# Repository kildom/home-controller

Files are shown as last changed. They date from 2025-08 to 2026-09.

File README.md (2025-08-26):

# home-controller

# Najnowsze ustalenia

* Nowy pomysł: Zrobić oddzielny moduł "gateway", zawiera:
  * Step-down 12->5V
  * alt 12V
  * Moduł RS-485
  * Mały mikrokontroler (np. AVR albo STM32C011F4P6) jako gateway między int. UART i RS-485
  * Złącza: GND, in 12V, in alt 12V, out 12V, out 5V, D+, D-, int. UART
  * Dzięki temu znika z tabeli poniżej: RS-485 i alt 12V
  * Gateway może informować local nodes: Output fifo full, voltage: 12V in, out, alt, 5V
* Jednak moduł STM32 zamiast 2 AVRów: [STM32F103C8T6](https://kamami.pl/zestawy-uruchomieniowe-stm32/1192915-kamod-bluepill-plytka-rozwojowa-z-mikrokontrolerem-stm32f103c8t6-kompatybilna-z-weact-bluepill-5906623487998.h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)
  * RS-485 (ten wymaga podłączenia do padów 5V-tolerant)
  * Piny podłączone do kwarca mogą być użyte, ale powinny mieć jednakowy stan, więc są traktowane razem jako jedno wyjście - połączone na płytce.
* Gotowe moduły step-down i RS-485 (ten wymaga podłączenia do padów 5V-tolerant)
* Kabel między-modułowy wymaga 2 przewodów: UART i 5V (opcjonalnie GND)
  * Albo może: zrezygnować z 2 IO na rzecz połączeń między-modułowych (wtedy też można usunąć `Shared RS-485+IO` z poniższej tabeli).
* Zaciski IO mogą być w jednym kawałku: https://mou.sr/4oknD5P
* Tabela z zasobami:

| | szt. | zaciski 230V | zaciski 12V | Pin µC | zaciski 230V | zaciski 12V | Pin µC |
| --- | ---- | --- | --- | --- | --- | --- | --- |
| Common 230V | 1 | 1 | | | 1 | 0 | 0 |
| Relays 230V common | 9 | 1 | | 1 | 9 | 0 | 9 |
| Relays 230V individual | 1 | 2 | | 1 | 2 | 0 | 1 |
| Relays 12V | 1 | | 2 | 1 | 0 | 2 | 1 |
| RS-485 | 1 | | | 3 | 0 | 0 | 3 |
| LED \* | 2 | | 2 | 2 | 0 | 4 | 4 |
| OC | 2 | | 1 | 1 | 0 | 2 | 2 |
| IO | 12 | | 1 | 1 | 0 | 12 | 12 |
| int. UART | 1 | | | 2 | 0 | 0 | 2 |
| GND | 1 | | 2 | | 0 | 2 | 0 |
| 12V | 1 | | 1 | | 0 | 1 | 0 |
| alt 12V | 1 | | 1 | | 0 | 1 | 0 |
| Shared RS-485+OC | 1 | | | \-1 | 0 | 0 | \-1 |
| Shared RS-485+IO | 2 | | | \-1 | 0 | 0 | \-2 |
| | | | | **RAZEM** | **12** | **24** | **31** |
| | | | | MAX | 12 | 24 | 31 |
| | | | | Pozostało | 0 | 0 | 0 |

# Inne

* Obudowa: [Kradex ZD1004J](https://botland.com.pl/obudowy/24954-obudowa-modulowa-kradex-zd1004j-abs-v0-na-szyne-din-652x898x716mm-jasnoszara-5905275033614.html)
* Przekaźniki: FORWARD INDUSTRIAL FRM18A-5
* Zaciski 230V: AK3001/6-KD-5.0/KIES
* Zaciski IO/12V: Phoenix Contact PTSA 0,5/ 8-2,5-Z 1990067
* Zabezpieczenie ESD: Littelfuse SP720
* Mikrokontroller: 2x AVR64DD28-I/SO
* Pojedynczy moduł:
  * 11 przekaźników:
    * 9x wspólny zmostkowany styk
    * 1x niezależny z dwoma stykami
    * 1x podłączony do strony styków IO/12V
  * 12 styków 230V
  * 22 styki IO/12V: 8 + 8 + 6
    * 2x2x LED driver
    * 2x Open-Collector
    * 14x IO
    * 1x2x Relay
  * 2x Złącze między modułami (żeby można było łączyć szeregowo):
    * Łączone przez złącze żeńskie kątowe na płytkach po bokach i kołki między modułami (bez kabla), np. [SL 22 164 10 G](https://www.tme.eu/pl/details/sl22.164.10.g)
      * Moduł wykonawczy i moduł zasilający mogą mieć płytki na różnych wysokościach (ok 1.4mm mod. zasilający jest wyżej), więc może trzeba obniżyć jedną, podnieś drugą, lutować złącza inaczej, albo wszystkiego po trochu.
    * 3x Masa
    * 5V
    * 2x 12V
    * UART
    * RS-485 rxd
    * RS-485 txd
    * RS-485 DE
      * W module zasilającym jest pull-down
      * W drugim zączu jest pull-up
      * W ten sposób kontroller będzie rozróżniał, czy został podłączony do moduły zasilającego i jest przekaźnikiem, czy też został podłączony do innego modułu i jest końcowym urządzeniem.
    * **Inna opcja**:
      * Użyć kabla z wieloma złączkami (jak stary kabel IDE)
      * Każdy moduł ma jedno złącze
      * Przewody RS-485 idą innym kablem (między modułowy będzie mieć wtedy 6 pinów, a RS-485 ma 4)
* Moduł zasilający
  * Stabilizator 12V->5V
  * Driver RS-485
  * Wiele wejść 12V: 1 podstawowe, 1 awaryjne
  * 1x Złącze między modułami
  * Zaciski:
    * 2x Masa
    * 2x 12V
    * 2x RS-485
  * Może zmieści się do:
    * Obudowa: [Kradex Z103J 88x34x62mm](https://botland.com.pl/obudowy/10131-obudowa-modulowa-kradex-z103j-88x34x62mm-na-szyne-din-jasna-5905275012343.html),
    * Zaciski: [TBJ05-03-1-G-G](https://www.tme.eu/pl/details/tbj05-03-1-g-g) (albo podobne na 6 torów)
    * Wszystkie zaciski powinny być z jednej strony (od strony niskiego napięcia)
  * **INNA OPCJA**
    * Dodać złącza na płytce dla gotowych układłów step-down i RS-485 i pozbyć się modułu zasilającego, np:
    * https://botland.com.pl/przetwornice-step-down/1349-d24v6f5-przetwornica-step-down-5v-06a-pololu-2107-5904422372132.html
    * https://kamami.pl/konwertery-rs485/574850-modttl-rs485-modul-konwertera-uart-rs-485-5906623456826.html

# Stare informacje

Sprzęt:
* Do skrzynek: NUCLEO-F446ZE https://kamami.pl/stm-nucleo-144/560902-nucleo-f446ze-plytka-rozwojowa-z-mikrokontrolerem-stm32f446zet6-5906623410026.html
* Do skrzynki komunikacyjnej: NUCLEO-F439ZI https://kamami.pl/stm-nucleo-144/572182-nucleo-f439zi-plytka-rozwojowa-z-mikrokontrolerem-stm32f439zit6-5906623410378.html
* Ochrona IO: SP720

Funkcjonalność:
* Napięcie zasilania: 12V, przekażniki, sterowanie diodami
* Napięcie mikrokontrolera: 3.3V
* Kilka wejść zasilania: jedno głowne (z dwiema diodami równolegle z niskim spadkiem), 3-4 dodatkowe z dwiema diodami szeregowo
* Zasilanie 230V jedno przy UPSie z przełączaniem na zasilanie awaryjne
* Wykrywanie jaki tryb zasilania jest aktualnie: normalny czy z UPSa
* Bezpiecznik w kaźdej skrzynce i jedna róźnicówka przy UPSie
* Komunikacja między kontrolerami przez powolny UART na RS-485
* Komunikacja ze światem zewnętrznym przez Ethernet i BLE
* Wyjścia przekażnikowe 230V (tylko NO wystarczą), dużo: lampy (też awaryjne), i rolety (2x na jedną roletę)
* Wyjścia LED, sterowanie prądem - wyjście PWM ze sprzęźeniem zwrotnym na ADC, wyrównanie napięcia przez R i C (PNP, NPN, 4 rezystory i kondensator)
* Wejścia-wyjścia niskonapięciowe 3.3V z SP720, kondensatorem i rezystorem
* Wejścia-wyjścia niskonapięciowe są do: przełączniki, komunikacja, i.t.p.
* Flashowanie za pośrednistwem Ethernet/BLE i rozsyłane dalej do kolenych płytek, jeżeli potrzeba

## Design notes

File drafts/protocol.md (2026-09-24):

# Network Layers

## 1. Physical Layer

* Medium:
  * CAN (tylko części elektryczna - sam driver MCP2562)
  * 1-wire half-duplex UART (open collector on TX + pull-up on RX)
  * 2-wire full-duplex UART (standardowy UART), ale tylko dla połączenia point-to-point, np Web Gateway.
    W tym przypadku negocjacja dostępu opisana poniżej może zostać wyłączona.
* Wszystkie urządzenia są równorzędne
* Łącze uznane jest za dostępne, jeżeli ostatni pakiet się zakończył lub nic nie jest transmitowane przed odpowiedni czas (w przypadku, gdy nie jest znany ostani pakiet)
* Jeżeli urządzenie chce nadawać, czeka losowy czas (rozkład zależny od długości kolejki, czasu oczekiwania pierwszego pakietu w kolejce i najwyższego priorytetu pakietów z kolejki)
  * OPCJA 1 (chyba lepsza) - Wysyła bajty: ESC, 2-3 losowe bajty, adres urządzenia, ESC (albo bajty jak w opcji 2)
    * Po każdym wysłanym bajcie czeka chwilę, żeby odebrać i potwierdzić, że prawidłowo wysłał i nie nastąpiła kolizja
    * Jeżeli nastąpiła kolizja, wraca do oczekiwania na dostępną linię. Dla kolizji poza ESC, czas oczekiwania jest proporcjonalny do `clz(bajt spodziewany XOR nadany)`.
      Dla ESC jest to losowy czas.
    * Między znakami ESC jest 3-4 bajty, więc nie zostanie to zinterpretowane jako pakiet danych.
  * OPCJA 2 - przyspieszenie i uproszczenie, ale zwiększone prawdopodobieństwo na więcej niż jedna kolizja z rzędu
    * Wysyła ramkę (z 2 bitami stopu): ESC, 4 bajty (gdzie niższe 2 bity to adres, 5 bitów losowych, najstarszy bit 1), ESC (UART jest LSB first)
      ```
        IDLE S DDDDDDDD ss S DDDDDDDD ss S DDDDDDDD ss S DDDDDDDD ss S DDDDDDDD ss S DDDDDDDD ss IDLE    | S - start bit, s - stop bit, D - data bit
      ------ 0 01010101 11 0 AARRRRR1 11 0 AARRRRR1 11 0 AARRRRR1 11 0 AARRRRR1 11 0 01010101 11 ------  | A - address bit, R - random bit
      ```
      This is probably more up to date and allow bigger shift between transmitters.
      ```
        IDLE S DDDDDDDD ss S DDDDDDDD ss S DDDDDDDD ss S DDDDDDDD ss S DDDDDDDD ss S DDDDDDDD ss IDLE    | S - start bit, s - stop bit, D - data bit
      ------ 0 11111111 11 0 AARR1111 11 0 AARR1111 11 0 AARR1111 11 0 AARR1111 11 0 11111111 11 ------  | A - address bit, R - random bit
             _ ‾‾‾‾‾‾‾‾ ‾‾ _ ::::‾‾‾‾ ‾‾ _ ::::‾‾‾‾ ‾‾ _ ::::‾‾‾‾ ‾‾ _ ::::‾‾‾‾ ‾‾ _ ‾‾‾‾‾‾‾‾ ‾‾
      ```
    * Taka konstrukcja ramki sprawia, że jeżeli nawet nadajniki będą przesunięte o 1 bit, to transmisja nadal będzie prawidłowa.
    * Jeżeli więcej niż jeden, to pojawią się będy transmisji, więc trzeba być przygotowanym na nie.
    * Po wysłaniu sprawdza, czy ramka jest taka jak powinna być, jeżeli tak, to przejmuje kontrolę nad linią, jeżeli nie, to czeka wyliczony czas.
    * Wyliczanie czasu:
      * Do wyliczania pomijamy bajty `ESC`.
      * `x = bajt wysłany XOR bajt odebrany` jest równe kolizji na spodziewanym stanie wysokim.
      * Jeżeli bity się nie za bardzo rozjechały, to
        każdy z nadajników będzie miał bity 1 tego wyrażenia na innych miejscach.
      * Jeżeli bity się rozjechały, to jeden z nadajników będzie miał bity 1 w miejscach, gdzie wysyłał 0, `d = 0 lub 1` w zależności, czy taka stuacja wystąpiła.
      * Czas oczekiwania będzie proporcjonalny do: `T + clz(x) + 32 * d`
      * Jeżeli tylko bajty `ESC` zostały zmodyfikowane, to czekaj `T + rand(0, 63)`
  * Wysyła ciąg dalszy pakietu
* Jeżeli pakiet przestał płynąć przez określony czas, następuje reset stanu.

## 2. Data Link Layer (TODO: Probably better)

* Format pakietu:
  ```
  |  1  |    1     | len  |   4   |  1  |  1   |      ESC = 0xFF
  | ESC | SUB_NEXT | DATA | CRC32 | ESC | STOP |      STOP = 0xFE
  |     BEGIN      |    CONTENT   |    END     |      len = 0..249
  ```
* Sposób dekodowania:
  1. Ustaw wskaźnik na SUB_NEXT
  2. Pobierz wartość ze wskaźnika do `tmp`
  3. Jeżeli `tmp` == 0xFD, zakończ
  4. Jeżeli `tmp` > 0xFD, oznacz pakiet jako uszkodzony i zakończ
  5. Inkrementuj wskaźnik o `tmp + 1`
  6. Jeżeli wskaźnik wyszedł poza pakiet, oznacz pakiet jako uszkodzony i zakończ
  7. Pobierz wartość ze wskaźnika do `tmp`
  8. Zapisz wartość ESC do wskaźnika
  9. Wróć do 3
* Sposób kodowania: bardzo prosty, odwrotny do dekodowania.
* Jeżeli wystąpił ponownie BEGIN, zakończ aktualny pakiet i rozpocznij nowy pakiet
* Jeżeli wystąpił STOP, zakończ pakiet i uznaj łącze za dostępne.
* Wszystkie bajty poza pakietem są ignorowane.
* Jeżeli urządzenie ma kilka pakietów do wysłania i łącznie nie przekraczają danego
  rozmiaru, to może wysłać jeden po drugim oddzielając je BEGIN, a END jest
  na końcu ostatniego pakietu.

## ~~2. Data Link Layer (OLD)~~

* Format pakietu:
  ```
  |  1  |  1   |   len     |     4      |  1  |  1   |      ESC = 0xFF
  | ESC | MASK | DATA^MASK | CRC32^MASK | ESC | STOP |      STOP = 0xFE
  |   BEGIN    |        CONTENT         |    END     |      len = 0..249
  ```
* Sposób wyznaczania `MASK`:
  * Zrób mapę występowania symboli w `DATA` i `CRC32`
  * Jeżeli `0xFF` nie występuje, `MASK` = 0
  * Zaznacz w mapie `0x00` i `0x01`.
  * Wybierz niewystępujący symbol `x` (przez to, że len <= 249, taki symbol zawsze istnieje).
  * Wyznacz `MASK = x ^ 0xFF`
* Jeżeli wystąpił ponownie BEGIN, zakończ aktualny pakiet i rozpocznij nowy pakiet
* Jeżeli wystąpił STOP, zakończ pakiet i uznaj łącze za dostępne.
* Wszystkie bajty poza pakietem są ignorowane.
* Jeżeli urządzenie ma kilka pakietów do wysłania i łącznie nie przekraczają danego
  rozmiaru, to może wysłać jeden po drugim oddzielając je BEGIN, a END jest
  na końcu ostatniego pakietu.

## 3. Network Layer

* Urządzenie ma adres 8-bitowy ustalany statycznie przez użytkownika przy rejestracji nowego urządzenia w sieci.
* Urządzenie ma nadaną przez użytkownika nazwę (string UTF-8).
* Urządzenie ma zmiennej długości unikalne ID pochodzące z hardware (np. ID mikrokontrolera). Pierszy bajt oznacza producenta.
* Router ma mapę adresów przypisującą adresy do portów fizycznych, np. jeżeli router
  ma dwa porty 1 i 2, to mapa posiada wartości:
  * 0 - urządzenie nie jest znane
  * 1 - urządzenie jest dostępne na porcie 1
  * 2 - urządzenie jest dostępne na porcie 2
  * Może to być zapisane na 2 bitach, więc mapa = 256 * 2 bity = 64 bajty.
  * Lub kompresując do 51 bajtów, gdzie jeden bajt opisuje 5 adresów używając
    mod/div przez 3. Trzeba pominąć też adres 0x00.
* Każdy pakiet zaczyna się od adresu źródłowego i jednego lub więcej adresów docelowych.
* Jeżeli router otrzyma pakiet, to uzupełnia swoją mapę na podstawie adresu źródłowego.
* Jeżeli adres docelowy nie jest znany, pakiet zostanie rozesłany na wszystkie porty oprócz tego, z którego przyszedł.
* Mapa może zostać zapisana do nieulotnej pamięci, jeżeli została zmieniona.
* Adres docelowy `0x00` to nowe urządzenie bez nadanego adresu.
* Router zawsze traktuje adres `0x00` jako nieznany (robi broadcast).
* Adres `0xFF` powinien być unikany, żeby zmniejszyć prawdopodobieństwo
  konieczności kodowania pakietu w niższej warstwie. Jednak nie jest zabroniony.
* Pusta lista adresów docelowych oznacza pakiet broadcast.
* Urządzenie po starcie wysyła pusty pakiet broadcast, żeby zarejestrować się w 
  sieci. Może to być kilka pakietów w losowych odstępach czasu. Jeżeli urządzenie
  przez dłuższy czas nie wysyłało żadnych pakietów broadcast, to wysyła taki pakiet ponownie.
* Ramka
  ```
  |   1   |  1  | 0..N  |  M   |
  | FLAGS | SRC | DST[] | DATA |

  FLAGS:
     |   7  |  6 5 4   |  3 2 1 0  |
     | zero | PROTOCOL | DST_COUNT |
  0 - Network Management Protocol
  1 - Application Layer Protocol
  2 - Bootloader Protocol
  ```

### Network Management Protocol

* DISCOVERY: Sprawdzenie obecności urządzeń:
  * Użytkownik wysyła pakiet DISCOVERY (broadcast).
  * Każde urządzenie odpowiada pakietem DISCOVERY_RESPONSE po
    losowym czasie od 0 do 5 sekund.
  * Router też odpowiada.
  * Jeżeli router przekazuje pakiet DISCOVERY_RESPONSE, to dodaje swój adres do listy.
  * Dodany wpis routera zawiera adres i numer portu.
  * Jeżeli router jest źródłem pakietu DISCOVERY_RESPONSE, to nie dodaje swojego adresu.
  * Odpowiedź zawiera numer portu, z którego przyszło DISCOVERY. Dla urządzenia
    końcowego jest to zawsze 0.
  * Do odpowiedzi dołącza swoje ID i nazwę.
  * Aplikacja użytkownika powinna zrobić discovery kilka razy, żeby zredukować 
    prawdopodobieństwo utraty pakietu.
  * Tylko jeden proces discovery powinien być aktywny w danym czasie.
  ```
  DISCOVERY (broadcast):
    |    1     |   1   |
    | Type = 0 | flags |
    flags:
      bit 0: response with broadcast
      bit 1: forget routing map (just for routers)

  DISCOVERY_RESPONSE (unicast to SRC or broadcast):
    |    1     |  1   |  1    | ID len |    1     | namelen |   2 * N   |
    | Type = 1 | port |ID len |   ID   | Name len |  NAME   | routers[] |
  ```

* SET_ADDRESS: Nadanie adresu nowemu urządzeniu (lub zmiana istniejącemu):
  * Użytkownik wysyła pakiet SET_ADDRESS (broadcast) z ID i przydzielonym adresem.
  * Urządzenie z danym ID ustawia swój adres na podany.
  * Odpowiada, że się udało, jeżeli nie odpowie, to trzeba spróbować ponownie.
  * Odpowiedź posiada już nowy adres w SRC.
  * Po zmianie adresu, aplikacja powinna zrobić discovery, z flagami "forget routing map" i "response with broadcast", żeby zaktualizować mapy w routerach.
  ```
  SET_ADDRESS (broadcast):
    |     1      |    1    |   1    | ID len |
    | Type = 2   | address | ID len |   ID   |

  SET_ADDRESS_RESPONSE (unicast to SRC):
    |    1     |    1    |   1    | ID len |
    | Type = 3 | address | ID len |   ID   |
  ```

* SET_NAME: Zmiana nazwy urządzenia:
  * Użytkownik wysyła pakiet SET_NAME (unicast) z nową nazwą.
  * Odpowiada, że się udało, jeżeli nie odpowie, to trzeba spróbować ponownie.
  ```
  SET_NAME (unicast):
    |     1      |      1    | name len |
    | Type = 4   |  name len |   NAME   |

  SET_NAME_RESPONSE (unicast to SRC):
    |    1     |      1    | name len |
    | Type = 5 |  name len |   NAME   |
  ```

* PACKET_LOST: Notyfikacja o utracie pakietu:
  * Router wysyła pakiet PACKET_LOST (unicast) do źródła pakietu, który nie mógł być dostarczony, np. przepełniona kolejka.
  ```
  PACKET_LOST (unicast to SRC):
    |     1      |
    | Type = 6   |
  ```

## 4. Application Layer

* Typy współdzielonych objektów:
  * Dane (exportowany stan urządzenia)
    * bool, int, e.t.c.
    * Urządzenie posiada tablicę pól stanu.
    * Każde pole ma pozycję (offset w bitach), liczbę bitów, typ.
    * Jeżeli stan pola się zmieni, to urządzenie wysyła broadcast z aktualnym stanem całego urządzenia.
      * Jeżeli to są dane, które nie muszą być często aktualizowane, to można wysłać po pewnym czasie lub przy okazji
        następnego broadcastu periodycznego.
    * Stan całego urządzenia jest wysyłany periodycznie co określony czas.
    * Urządzenie nadsłuchuje pakiety periodyczne innych urządzeń, analizuje czas pakietów zaraz przez i zaraz po,
      w celu przesunięcia nieznacznie swojego okresu, żeby odsunąć się jak najdalej od sąsiadów.
  * Sygnały
    * Urządzenie posiada tablicę sygnałów.
    * Inne urządzenie może wysłać pakiet unicast do tego urządzenia z sygnałem do wywołania.
    * Urządzenie potwierdza odbiór sygnału pakietem ACK do nadawcy.
    * Jeżeli nadawca nie otrzyma ACK w określonym czasie, to ponawia wysłanie sygnału.
    * Sygnał musi mieć licznik, żeby ignorować retansmisje.
    * Sygnał może mieć parametry
  * Event
    * Urządzenie może nadać broadcast z eventem.
    * W rzeczywistości jest to licznik w tablicy stanu, który przy zmianie jest rozpoznawany jako event.
    * Event może mieć parametry (też w tablicy stanu).
    * Odebrany pierwszy update stanu nie generuje eventu.
* Name resolution:
  * Dane i sygnały są rozpoznawane przez nazwę (unikalną dla cełej sieci), może zawierać kropki do grupowania.
  * Każde urządzenie posiada tablicę eksportowanych nazw z:
    * rodzajem (dane/sygnał),
    * pozycją,
    * typem i liczbą bitów (dla danych)
    * Tablica się nie zmienia nawet po restarcie urządzenia, ale może przy updacie aplikacji.
  * Oprócz tablicy, urządzenie posiada unikalny identyfikator tablicy inkrementowany przy każdym updacie aplikacji.
    * Identyfikator jest wysyłany przy każdym pakiecie z danymi lub sygnałem w celu weryfikacji zgodności.
    * Jeżeli urządzenie otrzyma pakiet stanu z innym identyfikatorem, to resetuje swoją dane importowanie i 
      rozpoczyna ponowne rozpoznawanie nazw dla tego urządzenia.
    * Jeżeli urządzenie otrzyma pakiet sygnału z innym identyfikatorem, to wsyła ACK z odpowiednim błędem do nadawcy
      i go ignoruje. Nadawca wtedy wie, że musi ponownie rozpoznać nazwy dla tego urządzenia.
  * Każdy importowany obiekt musi najpierw przejść procedurę rozpoznawania nazw:
    * Urządzenie wysyła pakiet broadcast, z nazwą obiektu do rozpoznania.
    * Urządzenie posiadające taki obiekt odpowiada pakietem unicast z rodzajem, pozycją, typem, liczbą bitów, i.t.p.
      Również wysyła swój identyfikator tablicy eksportu.
  * Dane importowane mogą być przechowywane w pamięci nieulotnej, żeby przyspieszyć start.
  * Importowanie przy pomocy indeksu objektu przydaje się, żeby odczytać wszystkie exporty z danego urządzenia.

```
IMPORT (broadcast):
  |     1      |    1      | name len |
  | Type = 1   |  name len |   NAME   |

IMPORT_BY_INDEX (unicast):
  |     1      |    1    |
  | Type = 2   |  index  |

EXPORT (unicast to SRC):
  |    1     |    1    |     1    | name len |    1    |  1   |       ...
  | Type = 3 |  index  | name len |   NAME   | tableId | kind | object details ...

EXPORT (wrong index, unicast to SRC):
  |    1     |    1    |       1        |
  | Type = 3 |  index  | name len = 255 |

SATATE (broadcast):
  |    1     |   1     |      N     |
  | Type = 4 | tableId | state data |

SIGNAL (unicast):
  |    1     |   1     | 1  |    1     | ...
  | Type = 5 | tableId | id | counter  | signal params ...

SIGNAL_ACK (unicast to SRC):
  |    1     | 1  |    1     |    1   |
  | Type = 6 | id | counter  | status |
                               ^- 0 - OK, 1 - tableId mismatch
```

## Bootloader Protocol

* Używany przez bootloader, który jest mocno ograniczony, np. nie ma DMA, IRQ - wszystko przez polling w pętli.
* Bootloader implementuje tylko `1. Physical Layer` (może być uproszczony), `2. Data Link Layer` i częściowo `3. Network Layer`.
* Nie ma `Network Management Protocol` a co za tym idzie, nie ma przypisanego adresu i nazwy.
* Adres jest zawsze 0, a identyfikuje się przez HW ID.
* Wszystkie pakiety do bootloadera są brodcast.
* Bootloader może przestać odbierać pakiety kiedy jest zajęty flashowaniem, więc sender musi na to uważać.
* Bootloader sprawdza poprawność aplikacji przy pomocy pierwszych 4 bajtów (ma to być wyrównany SP w pamięci RAM),
  więc programator powinien zacząć od erasu pierwszej strony, a zakończyć na piewszych 4 bajtach.
* Bootloader może być tylko startowany z aplikacji, więc aplikacja musi nadsłuchiwać tylko pakietu BOOT.
* Update bootloadera odbywa się przez wysłanie aplikacji, która nadpisze bootloader, a następnie oznaczy samą siebie
  jako niedokończona (erase pierwszej strony), żeby bootloader mógł wystartować.
* Podobny protokół może być używany do przesyłania wysokopoziomowej aplikacji. Wtedy ID nie jest potrzebny
  i wszystkie pakiety są unicast.

```
QUERY (broadcast):
  |    1     |
  | Type = 1 |

RESPONSE (unicast):
  |    1     |   1    | ID len | ...
  | Type = 2 | ID len |   ID   | device info: page size, flash size, HW model

ERASE (broadcast):
  |    1     |   1    | ID len |    4    |
  | Type = 3 | ID len |   ID   | address |

ERASE_DONE (unicast):
  |    1     |   1    | ID len |    4    |
  | Type = 4 | ID len |   ID   | address |

WRITE (broadcast):
  |    1     |   1    | ID len |    4    | ...  |
  | Type = 5 | ID len |   ID   | address | data |

WRITE_DONE (unicast):
  |    1     |   1    | ID len |    4    |  1  |
  | Type = 6 | ID len |   ID   | address | len |

READ (broadcast):
  |    1     |   1    | ID len |    4    |  1  |
  | Type = 7 | ID len |   ID   | address | len |

READ_DONE (unicast):
  |    1     |   1    | ID len |    4    | ...  |
  | Type = 8 | ID len |   ID   | address | data |

RESET (broadcast):
  |    1     |   1    | ID len |
  | Type = 9 | ID len |   ID   |

BOOT (unicast): tylko ten pakiet jest obsługiwany przez aplikację
  |    1      |
  | Type = 10 |
```

# <s>OLD STUFF</s>

## 1. Physical Layer (OLD)

* Medium:
  * Half duplex RS-485
  * Half duplex 1-wire UART
* Wszystkie urządzenia są równorzędne
* Urządzenie domyśnie jest w stanie nadsłuchiwania UART
* Łącze uznane jest za dostępne, jeżeli ostatni pakiet się zakończył lub nic nie jest transmitowane przed odpowiedni czas (w przypadku, gdy nie jest znany ostani pakiet)
* Jeżeli urządzenie chce nadawać, czeka losowy czas (rozkład zależny od długości kolejki, czasu oczekiwania pierwszego pakietu w kolejce i najwyższego priorytetu pakietów z kolejki)
  * Przechodzi to trybu GPIO
  * Ustawia DataOutput=0
  * Sprawdza ostani raz, czy nikt inny nie zaczął nadawania (stan niski)
  * Ustawia TxEnable=1
  * Czeka 1 Tbit
  * Ustawia DataOutput=1
  * Czeka ~0.25 Tbit
  * Ustawia TxEnable=0
  * Czeka 8.75 Tbit
  * Czeka losowy czas 0..10Tbit (włączając czasy ułamkowe)
  * Powtarza jeszcze 2 razy
  * Jeżeli w tym czasie wykryto, że ktoś inny chce nadawać zaprzestajemy nadawania, przechodzimy do trybu UART i czekamy określony czas zanim znowu uznamy łącze za dostępne.
  * Przechodzi do trybu UART, TxEnable=1
  * ```
      <-- 10 --><- 0..10 -><-- 10 --><- 0..10 -><-- 10 -->
    -- ---------........... ---------........... ---------DDDDDDDDDDD
      -                    -                    -         DDDDDDDDDDD
    ```
  * Przesyłamy pakiet
  * Przechodzi do trybu UART, TxEnable=0
  * Praktyczne podejście na STM32:
    * (RS-485)
    * Ustaw TIMER na one-pulse mode
    * DataOut = 0, wyłącz przerwania, sprawdza input, TxEn = 1, włącz TIMER, włącz przerwania
    * Timer po czasie 1 Tbit ustawia DataOut = 1, po 1.25 Tbit w przerwaniu ustawia TxEn = 0 i przełącza wejście na nadsłuchiwanie IRQ
    * Timer po czasie 10 + rand w przerwaniu ponawia próbę
    * LUB, jeżeli już nie ma więcej prób, timer po czasie 10 w przerwaniu rozpoczyna transmisję
    * (1-wire UART)
    * Idle: Tx=Hi-Z
    * Ustaw TIMER na one-pulse mode
    * wyłącz przerwania, sprawdza input, Tx=0, włącz TIMER, włącz przerwania
    * Timer po czasie 1 Tbit ustawia Tx=1, po 1.1 Tbit w przerwaniu ustawia Tx=Hi-Z i przełącza wejście na nadsłuchiwanie IRQ
    * Timer po czasie 10 + rand w przerwaniu ponawia próbę
    * LUB, jeżeli już nie ma więcej prób, timer po czasie 10 w przerwaniu rozpoczyna transmisję
* Jeżeli pakiet przestał płynąć przez określony czas, następuje reset stanu.

### 3. Network Layer

* Urządzenie ma dwa adresy 8-bitowe:
  * Adres fizyczny - ustalany statycznie przez automat, który jest wywoływany przez użytkownika przy rejestracji nowego urządzenia w sieci.
  * Adres logiczny - ustalany statycznie przez użytkownika przy rejestracji urządzenia w sieci.
  * W kodzie używany jest adres logiczny, istnieje potokół podobny do ARP do mapowania adresów logicznych na fizyczne.
  * W paczce używany jest adres fizyczny.
  * Adres fizyczny używany jest do routingu pakietów typu unicast lub multicast.
* Routing:
  * Jedna z szyn jest oznaczana jako "główna" (main).
  * Router dla każdego portu ma prefiks: adres i liczba najstarszych bitów
  * Dla portu skierowanego na "główną" szynę (bezpośrednio lub pośrednio) prefiks to 0/0 i jest sprawdzany jako ostatni.
* Przyznawanie adresu fizycznego:
  * Automat do przyznawania najpierw wykrywa topologię sieci przy pomocy pakietów DISCOVER
  * Tworzy drzewo sieci, gdzie korzeń to szyna główna
  * Od szyny odgałęziają się urządzania końcowe, routery i kolejne szyny
  * Każdy liść (urządzenie końcowe albo router) rezerwuje 0 bitów młodszych
  * Każdy węzeł (szyna) rezerwuje minimalną liczbę bitów młodszych, tak aby pomieścić wszystkie swoje dzieci:
    * bierze parę z najmniejszą liczbą bitów i łączy je:
      * dopisuje zera na początek do elementu z mniejszą liczbą bitów, żeby liczba bitów była równa
      * dopisuje 0 do jednej strony i 1 do drugiej
      * teraz para jest reprezentowana przez jeden element z liczbą bitów powiększoną o 1 i może się łączyć z innymi elementami
    * powtarza, aż zostanie jeden element
  * w ten sposób przyznane adresy wszystkich elementów w tej szynie (łącznie z podszynach)
  * Kolejne bity dopisane w późniejszym czasie staną się prefiksem tej szyny,
    który zostanie zapisany w tablicy routingu routera łączącego tą szynę
    z nadrzędną
  * Po przeprocesowaniu szyny głównej, wszystkie adresy zostają przyznane

```
| 1 |  1  |  1 |
|  SRC |  DST  | TYPE |

DISCOVERY:
    src: -
    dst: broadcast

DISCOVERY_RESPONSE:
    src: -
    dst: broadcast
    data: id, addresses[]

SET_ADDRESS:
    src: -
    dst: broadcast
    data: id, address

SET_NAME:
    src: -
    dst: address
    data: name

SET_ROUTING:
    src: -
    dst: address
    data: routing_table[]
        prefix: 11 bits
        side: 1 bit: 0-receiving side, 1-other side
        length: 4 bits

```

### Protokół niskopoziomowy

* Wszystkie urządzenia są równorzędne
* Urządzenie domyśnie jest w stanie nadsłuchiwania UART
* Łącze uznane jest za dostępne, jeżeli ostatni pakiet się zakończył lub nic nie jest transmitowane przed odpowiedni czas (w przypadku, gdy nie jest znany ostani pakiet)
* Jeżeli urządzenie chce nadawać, czeka losowy czas (rozkład zależny od długości kolejki, czasu oczekiwania pierwszego pakietu w kolejce i najwyższego priorytetu pakietów z kolejki)
  * Przechodzi to trybu GPIO
  * Ustawia DataOutput=0
  * Sprawdza ostani raz, czy nikt inny nie zaczął nadawania (stan niski)
  * Ustawia TxEnable=1
  * Czeka 1 Tbit
  * Ustawia DataOutput=1
  * Czeka ~0.25 Tbit
  * Ustawia TxEnable=0
  * Czeka 8.75 Tbit
  * Czeka losowy czas 0..10Tbit (włączając czasy ułamkowe)
  * Powtarza jeszcze 2 razy
  * Jeżeli w tym czasie wykryto, że ktoś inny chce nadawać zaprzestajemy nadawania, przechodzimy do trybu UART i czekamy określony czas zanim znowu uznamy łącze za dostępne.
  * Przechodzi do trybu UART, TxEnable=1
  * ```
      <-- 10 --><- 0..10 -><-- 10 --><- 0..10 -><-- 10 -->
    -- ---------........... ---------........... ---------DDDDDDDDDDD
      -                    -                    -         DDDDDDDDDDD
    ```
  * Przesyłamy pakiet
  * Przechodzi do trybu UART, TxEnable=0
  * Praktyczne podejście na STM32:
    * (RS-485)
    * Ustaw TIMER na one-pulse mode
    * DataOut = 0, wyłącz przerwania, sprawdza input, TxEn = 1, włącz TIMER, włącz przerwania
    * Timer po czasie 1 Tbit ustawia DataOut = 1, po 1.25 Tbit w przerwaniu ustawia TxEn = 0 i przełącza wejście na nadsłuchiwanie IRQ
    * Timer po czasie 10 + rand w przerwaniu ponawia próbę
    * LUB, jeżeli już nie ma więcej prób, timer po czasie 10 w przerwaniu rozpoczyna transmisję
    * (1-wire UART)
    * Idle: Tx=Hi-Z
    * Ustaw TIMER na one-pulse mode
    * wyłącz przerwania, sprawdza input, Tx=0, włącz TIMER, włącz przerwania
    * Timer po czasie 1 Tbit ustawia Tx=1, po 1.1 Tbit w przerwaniu ustawia Tx=Hi-Z i przełącza wejście na nadsłuchiwanie IRQ
    * Timer po czasie 10 + rand w przerwaniu ponawia próbę
    * LUB, jeżeli już nie ma więcej prób, timer po czasie 10 w przerwaniu rozpoczyna transmisję
    * 
* Format pakietu:
  ```
  |  1  |  1  |   len    |     4     |  1  |  1   |      ESC = 0xAA
  | ESC | XOR | DATA^XOR | CRC32^XOR | ESC | STOP |      STOP = 0xFF
  |   BEGIN   |       CONTENT        |    END     |      len = 0..249
  ```
  Sposób wyznaczania `XOR`:
  * Zrób mapę występowania symboli w `DATA` i `CRC32`
  * Jeżeli `0xAA` nie występuje, `XOR` = 0
  * Zaznacz w mapie `0x00` i `0x55`.
  * Wybierz niewystępujący symbol `x` (przez to, że len <= 249, taki symbol zawsze istnieje).
  * Wyznacz `XOR = x ^ 0xAA`
* Jeżeli pakiet przestał płynąć przez określony czas, następuje reset stanu.
* Jeżeli wystąpił ponownie BEGIN, rozpocznij nowy pakiet ignorując poprzedni
* Jeżeli wystąpił STOP, zakończ pakiet i uznaj łącze za dostępne.
* Ogólny overhead:
  * 5 bajtów na żądanie łącza
  * 4 bajty na BEGIN, END
  * 4 bajty na CRC32
  * 7 bajtów na odstęp między pakietami
  * 20 RAZEM bajtów / pakiet

### Protokół na wyższym poziomie

* Adres jest 12 bitowy
* Adresy i routowanie jest ustalane statycznie (np. przez interface www)
* Każde urządzenie posiada unikatowy ID, który zaczyna się od bajtu producenta i unikalnego ID nadanego przez producenta chipa
* Każde urządzenie zapamiętuje swój adres i string z jego nazwą (UTF-8)
* Nowe urządzenia mają adres 0 i są specyjalnie traktowane (może być kilka z takim adresem)
* Topologia sieci rozpoznawana jest przez wysłanie specyjanego pakietu brodcast DISCOVERY
  * Można wysłać kilka takich pakietów, żeby mieć pewność, że nie został zgubiony (albo jakaś odpowiedź na niego)
  * W odpowiedzi każde urządzenie odsyła swój adres, ID
  * Zapytanie o nazwę urządzenia odbywa się przez pakiet bezpośredni, żeby nie opciąrzać odpowiedzi DISCOVERY
  * Jeżeli taka odpowiedź przechodzi przez GW, to on dodaje swój adres
  * Urządzenia z adresem 0 też odsyłają taką odpowiedź
  * Na bazie topologi sieci można zmieniać adresy, nazwy i prefixy routowania dla GW
  * Urządzenia z adresem 0 są konfigurowane przez wysłanie pakietu brodcast zawierającego ID urządzenia (zamiast adresu)
* GW routuje pakiety na bazie prefixu, można zdefiniować, że dany prefix (lub kilka) jest po określonej stronie GW i wtedy GW nie rozsyła dalej pakietów jeżeli nie potrzeba

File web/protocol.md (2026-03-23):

# Network Layers

## 1. Physical Layer

* Medium:
  * CAN (only the electrical part – the MCP2562 driver itself), multiple devices on the same bus
  * UART (open collector on TX + pull-up on RX), multiple devices on the same line
  * UART full duplex one-to-one connection, two devices as usual UARTs, no collision handling needed, both devices can transmit at the same time
* Collision Handling
  * All devices are equal (peer-to-peer)
  * The link is considered available if the last packet has finished or nothing has been transmitted for an appropriate time (if the last packet is unknown)
  * If a device wants to transmit, it waits for a random time (distribution depends on queue length, waiting time of the first packet in the queue, and the highest packet priority in the queue)
    * OPTION 1 (probably better) – Sends bytes: ESC, 2–3 random bytes, device address, ESC (or bytes like in option 2)
      * After each sent byte, it waits briefly to receive and confirm correct transmission and detect collisions
      * If a collision occurs, it returns to waiting for a free line. For collisions outside ESC, waiting time is proportional to `clz(expected_byte XOR transmitted_byte)`.  
        For ESC, it is a random time.
      * There are 3–4 bytes between ESC characters, so it won’t be interpreted as a data packet.
    * OPTION 2 – faster and simpler, but higher probability of multiple consecutive collisions
      * Sends a frame (with 2 stop bits): ESC, 4 bytes (where the lower 2 bits are address, 5 random bits, MSB = 1), ESC (UART is LSB first)
        ```
          IDLE S DDDDDDDD ss S DDDDDDDD ss S DDDDDDDD ss S DDDDDDDD ss S DDDDDDDD ss S DDDDDDDD ss IDLE    | S - start bit, s - stop bit, D - data bit
        ------ 0 01010101 11 0 AARRRRR1 11 0 AARRRRR1 11 0 AARRRRR1 11 0 AARRRRR1 11 0 01010101 11 ------  | A - address bit, R - random bit
        ```
      * This frame structure ensures that even if transmitters are shifted by 1 bit, transmission remains valid
      * If more than one transmitter is active, transmission errors will occur, so this must be handled
      * After sending, it checks whether the frame is correct; if yes, it takes control of the line; otherwise, it waits a calculated time
      * Time calculation:
        * Ignore `ESC` bytes
        * `x = sent_byte XOR received_byte` corresponds to collision on expected HIGH state
        * If bits are not too misaligned, each transmitter will have 1 bits at different positions
        * If misaligned, one transmitter will have 1 bits where it sent 0; `d = 0 or 1` depending on whether this occurs
        * Waiting time is proportional to: `T + clz(x) + 32 * d`
        * If only `ESC` bytes were modified, wait `T + rand(0, 63)`
    * Sends the rest of the packet
  * If the packet stops flowing for a defined time, the state is reset

---

## 2. Data Link Layer

* Packet format:
  ```
  |  1  |  1   |   len     |     4      |  1  |  1   |      ESC = 0xFF
  | ESC | MASK | DATA^MASK | CRC32^MASK | ESC | STOP |      STOP = 0xFE
  |   BEGIN    |        CONTENT         |    END     |      len = 0..249
  ```

* How to determine `MASK`:
  * Build a map of symbol occurrences in `DATA` and `CRC32`
  * If `0xFF` does not occur, `MASK = 0`
  * Mark `0x00` and `0x01` in the map
  * Choose a symbol `x` that does not occur (since len ≤ 249, such a symbol always exists)
  * Compute `MASK = x ^ 0xFF`

* If BEGIN appears again, terminate the current packet and start a new one
* If STOP appears, terminate the packet and consider the link available
* All bytes outside packets are ignored
* If a device has multiple packets and their total size does not exceed a limit, it may send them consecutively separated by BEGIN, with END only at the end of the last packet

---

## 3. Network Layer

* Device has an 8-bit address assigned statically by the user during registration
* Device has a user-defined name (UTF-8 string)
* Device has a variable-length unique ID from hardware (e.g., microcontroller ID). First byte indicates manufacturer
* Router maintains an address map assigning addresses to physical ports:
  * 0 – device unknown
  * 1 – device reachable via port 1
  * 2 – device reachable via port 2
  * Can be stored in 2 bits → 256 * 2 bits = 64 bytes
  * Or compressed to 51 bytes using base-3 encoding (mod/div by 3), skipping address `0x00`

* Each packet starts with source address and one or more destination addresses
* When a router receives a packet, it updates its map based on the source address
* If destination is unknown, packet is broadcast to all ports except the incoming one
* Map may be stored in non-volatile memory when updated
* Destination address `0x00` means a new device without an assigned address
* Router always treats `0x00` as unknown (broadcast)
* Address `0xFF` should be avoided to reduce encoding needs in lower layers (but not forbidden)
* Empty destination list means broadcast
* On startup, a device sends an empty broadcast packet to register itself (possibly multiple times at random intervals)
* If no broadcast was sent for a long time, device sends one again

* Frame:
  ```
  |   1   |  1  | 0..N  |  M   |
  | FLAGS | SRC | DST[] | DATA |

  FLAGS:
     |   7  |  6 5 4   |  3 2 1 0  |
     | zero | PROTOCOL | DST_COUNT |

  0 - Network Management Protocol
  1 - Application Layer Protocol
  2 - Bootloader Protocol
  ```

---

### Network Management Protocol

#### DISCOVERY
* User sends DISCOVERY (broadcast)
* Each device responds with DISCOVERY_RESPONSE after random delay (0–5 s)
* Router also responds
* If router forwards response, it adds its address to the list
* Entry contains router address and port number
* If router is the source, it does not add itself
* Response includes port number from which DISCOVERY came (0 for end device)
* Includes device ID and name
* User application should repeat discovery multiple times to reduce packet loss probability
* Only one discovery process should be active at a time

```
DISCOVERY (broadcast):
  |    1     |   1   |
  | Type = 0 | flags |

  flags:
    bit 0: response with broadcast
    bit 1: forget routing map (routers only)
```

```
DISCOVERY_RESPONSE (unicast to SRC or broadcast):
  |    1     |  1   |  1    | ID len |    1     | namelen |   2 * N   |
  | Type = 1 | port |ID len |   ID   | Name len |  NAME   | routers[] |
```

---

#### SET_ADDRESS
* Assign or change device address
* User sends SET_ADDRESS (broadcast) with ID and new address
* Matching device sets its address
* Responds on success (retry if no response)
* Response uses new address as SRC
* After change, discovery should be run with flags to refresh routing maps

```
SET_ADDRESS (broadcast):
  |     1      |    1    |   1    | ID len |
  | Type = 2   | address | ID len |   ID   |
```

```
SET_ADDRESS_RESPONSE (unicast to SRC):
  |    1     |    1    |   1    | ID len |
  | Type = 3 | address | ID len |   ID   |
```

---

#### SET_NAME
* Change device name

```
SET_NAME (unicast):
  |     1      |      1    | name len |
  | Type = 4   |  name len |   NAME   |
```

```
SET_NAME_RESPONSE (unicast to SRC):
  |    1     |      1    | name len |
  | Type = 5 |  name len |   NAME   |
```

---

#### PACKET_LOST
* Router notifies source about undelivered packet

```
PACKET_LOST (unicast to SRC):
  |     1      |
  | Type = 6   |
```

---

## 4. Application Layer

### Shared object types

#### Data (device state)
* bool, int, etc.
* Device has an array of state fields
* Each field has bit offset, size, and type
* When a field changes, device broadcasts full state
* Less critical data may be delayed or piggybacked
* State is broadcast periodically
* Devices adjust their timing slightly to avoid collisions with neighbors

#### Signals
* Device has signal table
* Other device sends unicast signal
* Receiver responds with ACK
* If no ACK, sender retries
* Signal includes counter to avoid duplicates
* May include parameters

#### Events
* Broadcast events
* Implemented as counters in state table
* Change triggers event
* First received state does not generate event

---

### Name resolution

* Data and signals identified by unique names (UTF-8, may contain dots)
* Device has export table with:
  * type (data/signal)
  * position
  * type and bit size
* Table is persistent across reboot but changes with firmware updates
* Table has unique ID incremented on each update
  * Included in every data/signal packet
  * Mismatch triggers re-resolution or error

* Import process:
  * Device sends broadcast with object name
  * Owner responds with details + table ID

* Imported data may be cached in non-volatile memory

---

```
IMPORT (broadcast):
  |     1      |    1      | name len |
  | Type = 1   |  name len |   NAME   |
```

```
IMPORT_BY_INDEX (unicast):
  |     1      |    1    |
  | Type = 2   |  index  |
```

```
EXPORT (unicast to SRC):
  |    1     |    1    |     1    | name len |    1    |  1   | ...
  | Type = 3 |  index  | name len |   NAME   | tableId | kind | object details ...
```

```
STATE (broadcast):
  |    1     |   1     |      N     |
  | Type = 4 | tableId | state data |
```

```
SIGNAL (unicast):
  |    1     |   1     | 1  |    1     | ...
  | Type = 5 | tableId | id | counter  | signal params ...
```

```
SIGNAL_ACK (unicast to SRC):
  |    1     | 1  |    1     |    1   |
  | Type = 6 | id | counter  | status |
                               ^- 0 - OK, 1 - tableId mismatch
```

---

## Bootloader Protocol

* Used by a constrained bootloader (no DMA, IRQ – polling only)
* Implements:
  * Physical Layer (possibly simplified)
  * Data Link Layer
  * Part of Network Layer
* No Network Management Protocol → no address or name
* Address is always 0, identified by HW ID
* All packets to bootloader are broadcast
* Bootloader may stop receiving during flashing → sender must handle this
* Validates application via first 4 bytes (must be valid stack pointer)
* Programmer should erase first page first, and write first 4 bytes last
* Bootloader is started only from application → app must listen for BOOT packet
* Bootloader update:
  * Send application that overwrites bootloader
  * Then marks itself incomplete (erase first page) so bootloader starts

---

```
QUERY (broadcast):
  |    1     |
  | Type = 1 |
```

```
RESPONSE (unicast):
  |    1     |   1    | ID len | ...
  | Type = 2 | ID len |   ID   | device info
```

```
ERASE (broadcast):
  |    1     |   1    | ID len |    4    |
  | Type = 3 | ID len |   ID   | address |
```

```
WRITE (broadcast):
  |    1     |   1    | ID len |    4    | ...  |
  | Type = 5 | ID len |   ID   | address | data |
```

```
READ (broadcast):
  |    1     |   1    | ID len |    4    |  1  |
  | Type = 7 | ID len |   ID   | address | len |
```

```
RESET (broadcast):
  |    1     |   1    | ID len |
  | Type = 9 | ID len |   ID   |
```

```
BOOT (unicast – only handled by application):
  |    1      |
  | Type = 10 |
```

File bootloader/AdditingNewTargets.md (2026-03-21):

# If new chip is required

* Create new project in STM32CubeIDE
* Configure USARTs:
  * 8N1, no flow control
  * Overrun: DISABLE
* SYS:
  * Timebase source: None
* Clocks:
  * Internal should be good enough
* CRC:
  * Activate
* Set heap size to 0x000
* Override weak: `HAL_StatusTypeDef HAL_InitTick(uint32_t TickPriority) { return HAL_OK; }`.
* Advanced Settings:
  * All LL drivers (if possible)
* `main.c`:
  * Disable interrupts `__disable_irq();`
  * Deactivate CRC initialization `#if 0` ... `#endif` and add just `__HAL_RCC_CRC_CLK_ENABLE();`
  * In main loop:
    ```
    void uartPoll(USART_TypeDef *uart0, USART_TypeDef *uart1, USART_TypeDef *uart2, USART_TypeDef *uart3);
    uartPoll(USART1, USART2, NULL, NULL);
    ```
* Linker script:
  * Set flash size to 8K
  * Set RAM size to actual RAM size minus 8 bytes (for the bootloader magic bytes)
* `SystemInit()`:
  * Add `void bootSelect(); bootSelect();` at the beginning of the function
* If new microcontroller, edit `bootloader.c`:
  * Add new model
  * Check if the memory sizes are correct
  * Check if flash writing is correct
* Edit `patch.py`:

# If the same chip but different port configuration

* Create new build configurations in STM32CubeIDE
* Edit PORTx_BAUDRATE, PORTx_OC defines in new build configurations

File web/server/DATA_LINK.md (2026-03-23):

# Data Link Layer Implementation

This module implements Layer 2 (Data Link Layer) of the home-controller protocol, providing reliable packet transmission with CRC32 validation and collision avoidance through byte masking.

## Overview

The Data Link Layer handles:
- **Packet encoding**: Adds framing, masking, and CRC32 checksum
- **Packet decoding**: Parses raw serial data, validates CRC32, handles fragmentation
- **Byte masking**: Avoids ESC (0xFF) and STOP (0xFE) markers in transmitted data
- **Fragmented packet handling**: Reconstructs packets from misaligned/fragmented serial input

## Features

- ✅ Full protocol compliance with specification
- ✅ Robust CRC32 validation
- ✅ Automatic MASK calculation to avoid marker bytes
- ✅ Handles fragmented and misaligned packets
- ✅ Maximum data payload: 249 bytes per packet
- ✅ Async/await support
- ✅ Comprehensive test coverage

## Installation

Place `data_link.py` in your server directory alongside `serial_daemon.py`.

## Usage

### Sending Data

```python
import asyncio
import data_link
import serial_daemon

async def main():
    # Start serial daemon first
    await serial_daemon.start()
    await data_link.init()
    
    # Send data
    await data_link.data_link_send(b"Hello, Device!", end_with_stop=True)
    
    # Clean up
    await data_link.deinit()
    await serial_daemon.stop()

asyncio.run(main())
```

### Receiving Data

```python
import asyncio
import data_link
import serial_daemon

async def on_data_received(data: bytes):
    """Called when a valid packet is received"""
    print(f"Received: {data}")

async def main():
    # Start serial daemon first
    await serial_daemon.start()
    await data_link.init()
    
    # Set up callback for received packets
    await data_link.set_data_received_callback(on_data_received)
    
    # Keep running to receive data
    try:
        await asyncio.sleep(3600)  # Run for 1 hour
    except KeyboardInterrupt:
        pass
    
    # Clean up
    await data_link.deinit()
    await serial_daemon.stop()

asyncio.run(main())
```

## API Reference

### `async def data_link_send(data: bytes, end_with_stop: bool = True) -> None`

Send data via the Data Link Layer.

**Parameters:**
- `data`: Bytes or bytearray to transmit (0-249 bytes)
- `end_with_stop`: If True, append STOP byte to packet (default: True)

**Raises:**
- `ValueError`: If data exceeds 249 bytes
- `Exception`: If serial daemon not running

**Example:**
```python
await data_link.data_link_send(b"sensor_data", end_with_stop=True)
```

### `async def set_data_received_callback(callback: Callable[[bytes], None]) -> None`

Register callback function for received packets.

**Parameters:**
- `callback`: Async function that receives decoded packet data

**Example:**
```python
async def handle_packet(data: bytes):
    print(f"Got packet: {data.hex()}")

await data_link.set_data_received_callback(handle_packet)
```

### `async def init() -> None`

Initialize the Data Link Layer (called after serial daemon is running).

### `async def deinit() -> None`

Clean up Data Link Layer resources.

## Packet Format

Packets follow this structure as per protocol specification:

```
┌─────┬──────┬───────────┬────────────┬─────┬──────┐
│ ESC │ MASK │ DATA^MASK │ CRC32^MASK │ ESC │ STOP │
└─────┴──────┴───────────┴────────────┴─────┴──────┘
  1B    1B    0-249B        4B         1B    1B
```

Where:
- **ESC**: Frame marker (0xFF)
- **MASK**: Byte to XOR data/CRC32 (chosen to avoid ESC/STOP)
- **DATA^MASK**: User data XORed with MASK
- **CRC32^MASK**: CRC32 of original data, XORed with MASK  
- **STOP**: End marker (0xFE), optional based on `end_with_stop`

## MASK Calculation

The MASK byte is calculated to ensure that no byte in the encoded data matches ESC (0xFF) or STOP (0xFE):

1. If 0xFF doesn't appear in data+CRC32 → MASK = 0
2. Otherwise:
   - Mark 0x00 and 0x01 as reserved
   - Find unused byte `x`
   - MASK = x ⊕ 0xFF

This ensures XORing any data byte with MASK cannot produce 0xFF or 0xFE.

## Error Handling

The parser is robust against:
- **Fragmented packets**: Buffers incomplete data until complete
- **Misaligned packets**: Finds ESC markers and re-synchronizes
- **Invalid CRC**: Discards packets with CRC mismatch
- **Too-short packets**: Rejects packets < 5 bytes (MASK + 4-byte CRC32)
- **Double ESC bytes**: Treats as packet boundary or new packet start

Invalid packets are logged but don't crash the parser—it continues searching for the next valid packet.

## Limitations

- Maximum 249 bytes per packet (per protocol specification)
- Requires Python 3.7+ with `asyncio` support
- Depends on `serial_daemon.py` for serial port I/O

## Testing

Run the included test suite:

```bash
python3 test_data_link.py
```

Tests cover:
- CRC32 calculation consistency
- MASK calculation correctness
- Full encode/decode round-trip
- Error cases (oversized data, bad CRC, short packets)
- Packet format validation

## Protocol Notes

See `protocol.md` for the complete protocol specification, including:
- Physical layer (UART/CAN)
- Collision handling
- Multiple packets in sequence

## License

Part of home-controller project

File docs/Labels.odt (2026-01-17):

RES

D+

D-

UART

GND

+5V

+12V

GND

GND

BK12V

IN12V

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
UART

GND

+5V

+12V

GND

GND

BK12V

IN12V

+5V

RES

D+

D-

UART

GND

+5V

+12V

GND

GND

BK12V

IN12V

+5V

RES

D+

D-

UART

GND

+5V

+12V

GND

GND

BK12V

IN12V

+5V

RES

D+

D-

UART

GND

+5V

+12V

GND

GND

BK12V

IN12V

+5V

RES

D+

D-

UART

GND

+5V

+12V

GND

GND

BK12V

IN12V

+5V

RES

D+

D-

UART

GND

+5V

+12V

GND

GND

BK12V

IN12V

+5V

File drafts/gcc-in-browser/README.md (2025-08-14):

# Deprecated: Use GCC toolchain on Rapsberry Pi

---------------------------------

## old stuff 

Newest GCC crashes using CheerpX.

Switching to v86, but debian image must be highly optimized after installation, e.g.:
- remove unused kernel libraries,
- installation must be done with big image, shrinking should be done as the last step of optimization.
- v86 Source code can be changed, e.g. to better image download on demand (and maybe cache it in indexdb or window.caches)
- since image reads are predictable, some profiling can be done to allow optimal block downloading and/or pre-loading.
  - free space optimization tools: zerofree, e2image, and `cp` betweed two mounted images (apply all for best results)
  - create image format with block metadata that contains:
    - repeat count (if the same metadata are repeating for multiple blocks)
    - offset+size on disk, offset+size on image file (blocks can be non-equal)
    - compression method: 0 - none, 1 - block is filled with zeros, 2 - zstd
    - pre-load flag
    - note: this way disk does not to be shrinked a lot:
      - zero sectors will be saved as metadata
      - unneeded files will probably never downloaded and compressed with zstd

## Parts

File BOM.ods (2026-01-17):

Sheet: Sheet1
 |  |  |  |  |  |  |  |  |  |  |  |  |  |  |  | netto | brutto
 |  |  |  |  |  |  |  |  |  |  |  |  |  |  | TOTAL | 934.272808130081 | 1149.155554
5 | 1 | 5 |  |  | TME |  | Mouser |  | Kamami |  | Botland |  | Other
comm-board (io) | comm-board (gate) | io-board | Count | Name | URL | Price | URL | Price | URL | Price | URL | Price | URL | Price | Min price | Cost
H6,H5,H7,U4,J8,J9, J5, R15, R12, R11, R8, R3 | H6,H5,H7,J8,J9,J5, C8, D1, D6, R12, R11, R3, R4, R5, R6 | H6,H7,H5,R16 | 95 | No component – PCB only |  |  |  |  |  |  |  |  |  |  | 0.00 | 0.00
Case1 | Case1 |  | 6 | ZD1002J PC ABS V0 |  |  |  |  |  |  |  |  | https://www.kradex.com.pl/product/obudowy_modulowe_na_szyne_din/zd1002?lang=pl | 7.39837398373984 | 7.40 | 44.39
Case2 | Case2 |  | 6 | Filtr ZDFJ1002 |  |  |  |  |  |  |  |  | https://www.kradex.com.pl/product/akcesoria/zdf?lang=pl | 1.09756097560976 | 1.10 | 6.59
Case3 | Case3 |  | 3 | Maskownica ZD2TCJ |  |  |  |  |  |  |  |  | https://www.kradex.com.pl/product/akcesoria/zd2tc?lang=pl | 3.09756097560976 | 3.10 | 9.29
U1 | U1,U4 |  | 7 | MAX485ECPA+ | https://www.tme.eu/pl/details/sn75176bp/uklady-scalone-rs232-rs422-rs485/texas-instruments/ | 3.93 | https://mou.sr/3MV8M3A | 38.7 |  |  |  |  |  |  | 3.93 | 27.51
J1 |  |  | 5 | Step-down | https://www.tme.eu/pl/details/df-dfr0831/przetwornice/dfrobot/dfr0831/ | 23.0731707317073 |  |  | https://kamami.pl/step-upstep-down/1178565-modul-przetwornicy-step-upstep-down-5v1a-s13v10f5-pololu-4083-5906623413195.html | 32.88 | https://botland.com.pl/przetwornice-step-up-step-down/21021-s13v15f5-przetwornica-step-upstep-down-5v-15a-pololu-4084.html | 36.5 | https://mou.sr/44Y6ff7 | 18.1 | 18.10 | 90.50
 | J1 |  | 1 | L7805CV |  |  | https://mou.sr/4sithHr | 1.85 |  |  |  |  |  |  | 1.85 | 1.85
U2 | U2 |  | 6 | LF33ABV – 3.3V Reg | https://www.tme.eu/pl/details/lf33abv/stabilizatory-napiecia-nieregulowane-ldo/stmicroelectronics/ | 2.033 |  |  |  |  |  |  |  |  | 2.03 | 12.20
J6, J7 | J6, J7 |  | 12 | PTSA-0.5-6-2.5-Z | https://www.tme.eu/pl/details/ptsa0.5_6-2.5-z/listwy-zaciskowe-do-druku/phoenix-contact/1990041/ | 5.2 | https://mou.sr/4pgvkcA | 3.51 |  |  |  |  |  |  | 3.51 | 42.12
U3 | U3 |  | 6 | STM32C011F6P | https://www.tme.eu/pl/details/stm32c011f6p6/mikrokontrolery-st/stmicroelectronics/ | 4.48 | https://mou.sr/4pevyRa | 3.1 |  |  |  |  |  |  | 3.10 | 18.60
Y1 | Y1 |  | 6 | XTAL 20MHz | https://www.tme.eu/pl/details/20m-49s-sr/rezonatory-kwarcowe-tht/sr-passives/ | 2.5 |  |  |  |  |  |  |  |  | 2.50 | 15.00
J4 | J4 |  | 6 | Header male 1x4 | https://www.tme.eu/pl/details/77311-118-36lf/listwy-i-gniazda-kolkowe/amphenol-communications-solutions/ | 1 |  |  |  |  |  |  |  |  | 1.00 | 6.00
C1,C2,C9 | C1,C2,C9 |  | 18 | Cap 10nF 50V | https://www.tme.eu/pl/details/cc-10n/kondensatory-ceramiczne/sr-passives/ | 0.08 |  |  |  |  |  |  |  |  | 0.08 | 1.44
C3 | C3 |  | 6 | Cap 2.2uF 50V | https://www.tme.eu/pl/details/fg14x7r1h225krt06/kondensatory-mlcc-tht/tdk/ | 1.8 |  |  |  |  |  |  |  |  | 1.80 | 10.80
C4, C5 | C4, C5 |  | 12 | Cap 4.7uF 25V | https://www.tme.eu/pl/details/fg14x7r1e475krt06/kondensatory-mlcc-tht/tdk/ | 1.6 |  |  |  |  |  |  |  |  | 1.60 | 19.20
C6, C7 | C6, C7 |  | 12 | Cap 33pF | https://www.tme.eu/pl/details/cc-33_100/kondensatory-ceramiczne/sr-passives/ | 0.1 |  |  |  |  |  |  |  |  | 0.10 | 1.20
C8 |  |  | 5 | Cap 220pF | https://www.tme.eu/pl/details/cc-220/kondensatory-ceramiczne/sr-passives/ | 0.07 |  |  |  |  |  |  |  |  | 0.07 | 0.35
D1,D6,D7,D8 | D7, D8 |  | 22 | BAT42 – Schottky (ESD) | https://www.tme.eu/pl/details/bat42/diody-schottky-tht/stmicroelectronics/ | 0.0949 |  |  |  |  |  |  |  |  | 0.09 | 2.09
D3, D4 | D3, D4 |  | 12 | SB240TA 2A 40V 0.5V – prost. Schottky | https://www.tme.eu/pl/details/sb240ta-smc/diody-schottky-tht/smc-diode-solutions/sb240ta/ | 0.32 |  |  |  |  |  |  |  |  | 0.32 | 3.84
D2 | D2 |  | 6 | FR203GTA 2A 200V 1.3V – prost. | https://www.tme.eu/pl/details/fr203gta-smc/diody-uniwersalne-tht/smc-diode-solutions/fr203gta/ | 0.35 |  |  |  |  |  |  |  |  | 0.35 | 2.10
R7 | R7 |  | 6 | R TTH 33K |  |  |  |  | https://kamami.pl/rezystory/1184126-ckx8641-zestaw-rezystorow-025w-1-2600--5906623499120.html | 0.0265 |  |  |  |  | 0.03 | 0.16
R13 | R13 |  | 6 | R TTH 6.2K |  |  |  |  |  |  |  |  |  |  | 0.00 | 0.00
R9 | R9 |  | 6 | Wire |  |  |  |  |  |  |  |  |  |  | 0.00 | 0.00
R14 | R14,R15 |  | 7 | R TTH 120 |  |  |  |  |  |  |  |  |  |  | 0.00 | 0.00
R2 | R2,R8 |  | 7 | R TTH 22K |  |  |  |  |  |  |  |  |  |  | 0.00 | 0.00
R6 |  |  | 5 | R TTH 470 |  |  |  |  |  |  |  |  |  |  | 0.00 | 0.00
R5 |  |  | 5 | R TTH 47K |  |  |  |  |  |  |  |  |  |  | 0.00 | 0.00
R4 |  |  | 5 | R TTH 220 |  |  |  |  |  |  |  |  |  |  | 0.00 | 0.00
TVS1,2,3 | TVS1,2,3,4,5,6 |  | 21 | RS-485 ESD protection | https://www.tme.eu/pl/details/p6ke6.8ca-dio/diody-tvs-tht-dwukierunkowe/diotec-semiconductor/p6ke6-8ca/ | 1.065 |  |  |  |  |  |  |  |  | 1.07 | 22.37
 |  | Q1,2,3,4,5,6,7,8,9, 10,11,12,14,16,17 | 75 | NPN SMD BC847C-AQ | https://www.tme.eu/pl/details/bc847c-aq-dio/tranzystory-npn-smd/diotec-semiconductor/bc847c-aq/ | 0.0764 |  |  |  |  |  |  |  |  | 0.08 | 5.73
 |  | R1,2,3,4,5,6,7,8,9, 10,11,47,49,48,52, 39,40,41,44,56,57 | 105 | Res 0805 2.2K | https://www.tme.eu/pl/details/smd0805-2k2/rezystory-smd/royalohm/0805s8j0222t5e/ | 0.0569 |  |  |  |  |  |  |  |  | 0.06 | 5.97
 |  | D1,2,3,4,5,6,7,8,9, 10,11,12,13,14, 15,16,17,18,19, 20,21 | 105 | Diode Vishay MCL4448-TR | https://www.tme.eu/pl/details/mcl4448-tr/diody-uniwersalne-smd/vishay/ | 0.2908 |  |  |  |  |  |  |  |  | 0.29 | 30.53
 |  | K1,2,3,4,5,6,7,8,9, 10,11 | 55 | Relay FRM18A-5 DC12V | https://www.tme.eu/pl/details/frm18a-12vdc/przekazniki-elektromagn-miniaturowe/forward-industrial-co/frm18a-5-dc12v/ | 5.30081300813008 |  |  |  |  |  |  |  |  | 5.30 | 291.54
 |  | U2 | 5 | Kamod BluePill+ |  |  |  |  | https://kamami.pl/zestawy-uruchomieniowe-stm32/1193836-kamod-bluepill-plytka-ewaluacyjna-z-mikrokontrolerem-stm32f103c8t6-kompatybilna-z-bluepill-wlutowane-zl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 | 17.62 |  |  |  |  | 17.62 | 88.10
 |  | C1,2,3,4,5,6,7,8,9, 10,11,12,13,14, 15, 18 | 80 | Cap 0805 220pF | https://www.tme.eu/pl/details/cl21c221jbannnc/kondensatory-mlcc-smd/samsung/ | 0.0571 |  |  |  |  |  |  |  |  | 0.06 | 4.57
 |  | C16, 17, 19 | 15 | Cap 0805 10uF | https://www.tme.eu/pl/details/cl21a106kaynnne/kondensatory-mlcc-smd/samsung/ | 0.2027 |  |  |  |  |  |  |  |  | 0.20 | 3.04
 |  | U1 | 5 | ESD – SP720ABG | https://www.tme.eu/pl/details/sp720abg/diody-zabezpieczajace-drabinki/littelfuse/ | 9.9 | https://mou.sr/3YfRxfR | 7.1 |  |  |  |  |  |  | 7.10 | 35.50
 |  | J5 | 5 | Low volt. header Phoenix Contact 1990232 |  |  | https://mou.sr/4oknD5P | 13.76 |  |  |  |  |  |  | 13.76 | 68.80
 |  | J1,2,3,4 | 20 | High volt. header DG128-5.0-03P-14-00A(H) | https://www.tme.eu/pl/details/dg128-5.0-03p14/listwy-zaciskowe-do-druku/degson-electronics/dg128-5-0-03p-14-00a-h/ | 1.419 |  |  |  |  |  |  |  |  | 1.42 | 28.38
 |  | C20,21,23,24 | 20 | Cap 1210 47uF | https://www.tme.eu/pl/details/c3216x5r1e476mac/kondensatory-mlcc-smd/tdk/c3216x5r1e476m160ac/ | 1.691 |  |  |  |  |  |  |  |  | 1.69 | 33.82
 |  | Q13,15 | 10 | PNP SMD BC857C-AQ | https://www.tme.eu/pl/details/bc857c-aq-dio/tranzystory-pnp-smd/diotec-semiconductor/bc857c-aq/ | 0.0693 |  |  |  |  |  |  |  |  | 0.07 | 0.69
 |  | R51,54,43,45 | 20 | Res 0805 68 |  |  |  |  |  |  |  |  |  |  | 0.00 | 0.00
 |  | R46,53 | 10 | Res 0805 100 |  |  |  |  |  |  |  |  |  |  | 0.00 | 0.00
 |  | R22 | 5 | Res 0805 220 |  |  |  |  |  |  |  |  |  |  | 0.00 | 0.00
 |  | R55 | 5 | Res 0805 47K |  |  |  |  |  |  |  |  |  |  | 0.00 | 0.00
 |  | R17 | 5 | Res 0805 470 |  |  |  |  |  |  |  |  |  |  | 0.00 | 0.00
 |  | R12,13,14,15,18,19, 20,21,23,24,25,26, 27,28,29,30,31,32, 33,34,35,36,37,38 | 120 | Res 0805 150 |  |  |  |  |  |  |  |  |  |  | 0.00 | 0.00
 |  | U1-hdr1, U1-hdr2 | 10 | Header female 1x20 | https://www.tme.eu/pl/details/zl262-20sg/listwy-i-gniazda-kolkowe/connfly/ds1023-1-20s21/ | 0.832 |  |  |  |  |  |  |  |  | 0.83 | 8.32
 |  | Case1 | 5 | ZD1004J ABS V0 |  |  |  |  |  |  |  |  | https://www.kradex.com.pl/product/obudowy_modulowe_na_szyne_din/zd1004j_abs_v0?lang=pl | 11.349593495935 | 11.35 | 56.75
 |  | Case2 | 5 | ZDFJ1004 ABS V0 |  |  |  |  |  |  |  |  | https://www.kradex.com.pl/product/akcesoria/zdfj1004_abs_v0?lang=pl | 1.2520325203252 | 1.25 | 6.26
 |  | Case3 | 2.5 | ZD4TCJ ABS V0 |  |  |  |  |  |  |  |  | https://www.kradex.com.pl/product/akcesoria/zd4tc?lang=pl | 3.7479674796748 | 3.75 | 9.37
 |  | Screw1,2,3,4 | 20 | Wkręt 5001404 | https://www.tme.eu/pl/details/b2.9x8_bn14065/wkrety/bossard/5001404/ | 0.062 |  |  |  |  |  |  |  |  | 0.06 | 1.24
 |  | Pad1,2,3,4 | 20 | Podkładka M3 PA6 |  |  |  |  |  |  |  |  | https://allegro.pl/oferta/m3-podkladka-nylonowa-plastikowa-plaska-pa6-20sz-8537598758 | 0.12 | 0.12 | 2.40
 |  | Pasta | 0 | Pasta lut. |  |  |  |  |  |  |  |  |  |  | 0.00 | 0.00
 |  | Penceta | 0 | Penceta do SMD |  |  |  |  |  |  |  |  |  |  | 0.00 | 0.00
 |  |  | 0 |  |  |  |  |  |  |  |  |  |  |  | 0.00 | 0.00
 |  |  | 0 |  |  |  |  |  |  |  |  |  |  |  | 0.00 | 0.00
 |  |  | 0 |  |  |  |  |  |  |  |  |  |  |  | 0.00 | 0.00
 |  |  | 0 |  |  |  |  |  |  |  |  |  |  |  | 0.00 | 0.00
 |  |  | 0 |  |  |  |  |  |  |  |  |  |  |  | 0.00 | 0.00
 |  |  | 0 |  |  |  |  |  |  |  |  |  |  |  | 0.00 | 0.00
 |  |  | 0 |  |  |  |  |  |  |  |  |  |  |  | 0.00 | 0.00
 |  |  | 0 |  |  |  |  |  |  |  |  |  |  |  | 0.00 | 0.00
 |  |  | 0 |  |  |  |  |  |  |  |  |  |  |  | 0.00 | 0.00
 |  |  | 0 |  |  |  |  |  |  |  |  |  |  |  | 0.00 | 0.00
 |  |  | 0 |  |  |  |  |  |  |  |  |  |  |  | 0.00 | 0.00
 |  |  | 0 |  |  |  |  |  |  |  |  |  |  |  | 0.00 | 0.00
 |  |  | 0 |  |  |  |  |  |  |  |  |  |  |  | 0.00 | 0.00
 |  |  | 0 |  |  |  |  |  |  |  |  |  |  |  | 0.00 | 0.00
 |  |  | 0 |  |  |  |  |  |  |  |  |  |  |  | 0.00 | 0.00
 |  |  | 0 |  |  |  |  |  |  |  |  |  |  |  | 0.00 | 0.00
 |  |  | 0 |  |  |  |  |  |  |  |  |  |  |  | 0.00 | 0.00
 |  |  | 0 |  |  |  |  |  |  |  |  |  |  |  | 0.00 | 0.00
 |  |  | 0 |  |  |  |  |  |  |  |  |  |  |  | 0.00 | 0.00
 |  |  | 0 |  |  |  |  |  |  |  |  |  |  |  | 0.00 | 0.00
 |  |  | 0 |  |  |  |  |  |  |  |  |  |  |  | 0.00 | 0.00
 |  |  | 0 |  |  |  |  |  |  |  |  |  |  |  | 0.00 | 0.00
 |  |  | 0 |  |  |  |  |  |  |  |  |  |  |  | 0.00 | 0.00
 |  |  | 0 |  |  |  |  |  |  |  |  |  |  |  | 0.00 | 0.00
 |  |  | 0 |  |  |  |  |  |  |  |  |  |  |  | 0.00 | 0.00
 |  |  | 0 |  |  |  |  |  |  |  |  |  |  |  | 0.00 | 0.00
 |  |  | 0 |  |  |  |  |  |  |  |  |  |  |  | 0.00 | 0.00
 |  |  | 0 |  |  |  |  |  |  |  |  |  |  |  | 0.00 | 0.00
 |  |  | 0 |  |  |  |  |  |  |  |  |  |  |  | 0.00 | 0.00
 |  |  | 0 |  |  |  |  |  |  |  |  |  |  |  | 0.00 | 0.00
 |  |  | 0 |  |  |  |  |  |  |  |  |  |  |  | 0.00 | 0.00
 |  |  | 0 |  |  |  |  |  |  |  |  |  |  |  | 0.00 | 0.00
 |  |  | 0 |  |  |  |  |  |  |  |  |  |  |  | 0.00 | 0.00
 |  |  | 0 |  |  |  |  |  |  |  |  |  |  |  | 0.00 | 0.00
 |  |  | 0 |  |  |  |  |  |  |  |  |  |  |  | 0.00 | 0.00
 |  |  | 0 |  |  |  |  |  |  |  |  |  |  |  | 0.00 | 0.00
 |  |  | 0 |  |  |  |  |  |  |  |  |  |  |  | 0.00 | 0.00
 |  |  | 0 |  |  |  |  |  |  |  |  |  |  |  | 0.00 | 0.00
 |  |  | 0 |  |  |  |  |  |  |  |  |  |  |  | 0.00 | 0.00
 |  |  | 0 |  |  |  |  |  |  |  |  |  |  |  | 0.00 | 0.00
 |  |  | 0 |  |  |  |  |  |  |  |  |  |  |  | 0.00 | 0.00
 |  |  | 0 |  |  |  |  |  |  |  |  |  |  |  | 0.00 | 0.00
 |  |  | 0 |  |  |  |  |  |  |  |  |  |  |  | 0.00 | 0.00
 |  |  | 0 |  |  |  |  |  |  |  |  |  |  |  | 0.00 | 0.00
 |  |  | 0 |  |  |  |  |  |  |  |  |  |  |  | 0.00 | 0.00
 |  |  | 0 |  |  |  |  |  |  |  |  |  |  |  | 0.00 | 0.00
 |  |  | 0 |  |  |  |  |  |  |  |  |  |  |  | 0.00 | 0.00
 |  |  | 0 |  |  |  |  |  |  |  |  |  |  |  | 0.00 | 0.00
 |  |  | 0 |  |  |  |  |  |  |  |  |  |  |  | 0.00 | 0.00
 |  |  | 0 |  |  |  |  |  |  |  |  |  |  |  | 0.00 | 0.00
 |  |  | 0 |  |  |  |  |  |  |  |  |  |  |  | 0.00 | 0.00
 |  |  | 0 |  |  |  |  |  |  |  |  |  |  |  | 0.00 | 0.00
 |  |  | 0 |  |  |  |  |  |  |  |  |  |  |  | 0.00 | 0.00
 |  |  | 0 |  |  |  |  |  |  |  |  |  |  |  | 0.00 | 0.00
 |  |  | 0 |  |  |  |  |  |  |  |  |  |  |  | 0.00 | 0.00
 |  |  | 0 |  |  |  |  |  |  |  |  |  |  |  | 0.00 | 0.00
 |  |  | 0 |  |  |  |  |  |  |  |  |  |  |  | 0.00 | 0.00
 |  |  | 0 |  |  |  |  |  |  |  |  |  |  |  | 0.00 | 0.00
 |  |  | 0 |  |  |  |  |  |  |  |  |  |  |  | 0.00 | 0.00
 |  |  | 0 |  |  |  |  |  |  |  |  |  |  |  | 0.00 | 0.00
 |  |  | 0 |  |  |  |  |  |  |  |  |  |  |  | 0.00 | 0.00
 |  |  | 0 |  |  |  |  |  |  |  |  |  |  |  | 0.00 | 0.00
 |  |  | 0 |  |  |  |  |  |  |  |  |  |  |  | 0.00 | 0.00
 |  |  | 0 |  |  |  |  |  |  |  |  |  |  |  | 0.00 | 0.00
 |  |  | 0 |  |  |  |  |  |  |  |  |  |  |  | 0.00 | 0.00
 |  |  | 0
 |  |  | 0
 |  |  | 0
 |  |  | 0
 |  |  | 0
 |  |  | 0

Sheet: Sheet2
UART simulation: | https://www.falstad.com/circuit/circuitjs.html

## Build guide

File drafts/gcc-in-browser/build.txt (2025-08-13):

docker build -t audit-container-32 .

docker run -it --rm \
  --cap-add=AUDIT_CONTROL \
  --cap-add=SYS_ADMIN \
  --security-opt apparmor=unconfined \
  audit-container-32

docker run -it --rm \
  --cap-add=AUDIT_CONTROL \
  --cap-add=SYS_ADMIN \
  --security-opt apparmor=unconfined \
  audit-container-32

root@cb1068eb9b43:/# service auditd start
Starting audit daemon: auditd failed!

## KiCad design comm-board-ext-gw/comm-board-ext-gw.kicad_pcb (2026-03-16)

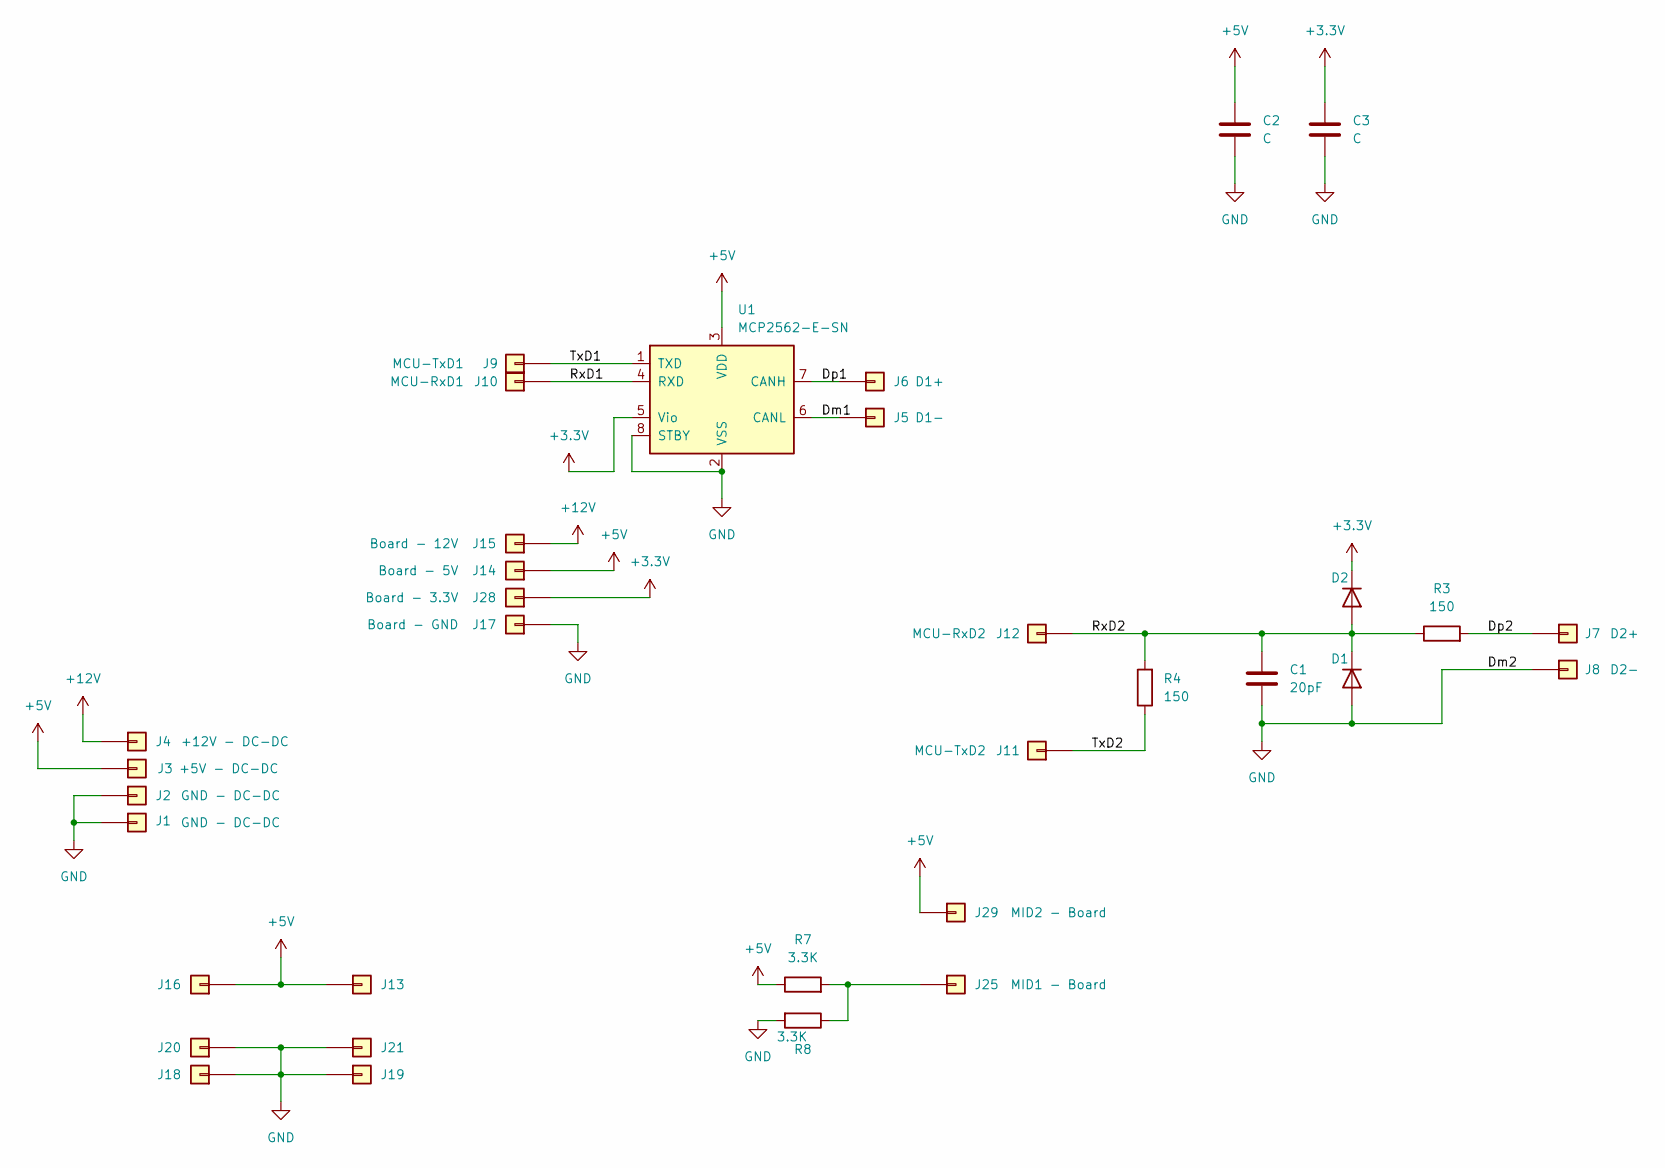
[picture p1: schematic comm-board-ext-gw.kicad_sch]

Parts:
C1: 20pF; CNC-mill-0.7-CAP
C2, C3: C; CNC-mill-0.7-CAP
D1, D2: D; CNC-mill-0.7-RES
J1, J2: GND - DC-DC; CHDR
J3: +5V - DC-DC; CHDR
J4: +12V - DC-DC; CHDR
J5: D1-; CHDR
J6: D1+; CHDR
J7: D2+; CHDR
J8: D2-; CHDR
J9: MCU-TxD1; CHDR
J10: MCU-RxD1; CHDR
J11: MCU-TxD2; CHDR
J12: MCU-RxD2; CHDR
J13, J16, J18, J19, J20, J21: CHDR
J14: Board - 5V; CHDR
J15: Board - 12V; CHDR
J17: Board - GND; CHDR
J25: MID1 - Board; CHDR
J28: Board - 3.3V; CHDR
J29: MID2 - Board; CHDR
R3, R4: 150; CNC-mill-0.7-RES
R7, R8: 3.3K; CNC-mill-0.7-RES
U1: MCP2562-E-SN; CNC-mill-0.8-DIP-8

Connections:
+3.3V: C3.1, D2.1 (K), J28.1, U1.5 (Vio)
+5V: C2.1, J3.1, J13.1, J14.1, J16.1, J29.1, R7.1, U1.3 (VDD)
+12V: J4.1, J15.1
/Dm1: J5.1, U1.6 (CANL)
/Dp1: J6.1, U1.7 (CANH)
/Dp2: J7.1, R3.2
/RxD1: J10.1, U1.4 (RXD)
/RxD2: C1.1, D1.1 (K), D2.2 (A), J12.1, R3.1, R4.2
/TxD1: J9.1, U1.1 (TXD)
/TxD2: J11.1, R4.1
GND: C1.2, C2.2, C3.2, D1.2 (A), J1.1, J2.1, J8.1, J17.1, J18.1, J19.1, J20.1, J21.1, R8.2, U1.2 (VSS), U1.8 (STBY)
unnamed: J25.1, R7.2, R8.1

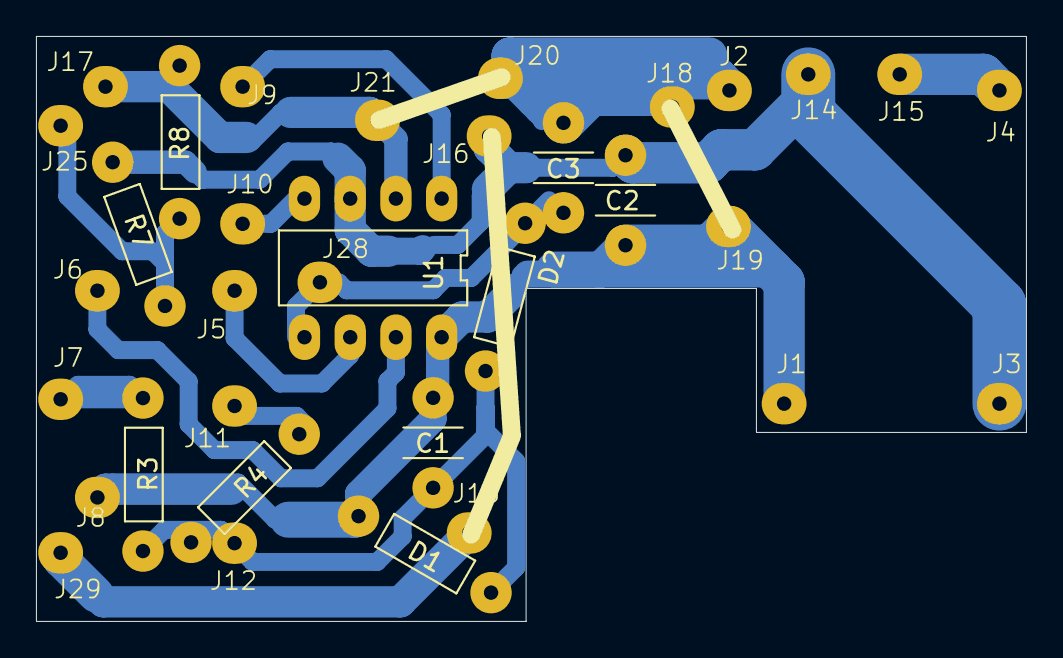
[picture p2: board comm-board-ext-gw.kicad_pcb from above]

Board: 4 copper layers, 55.0 x 32.5 mm, 34 parts (0 on the bottom side), 12 nets.

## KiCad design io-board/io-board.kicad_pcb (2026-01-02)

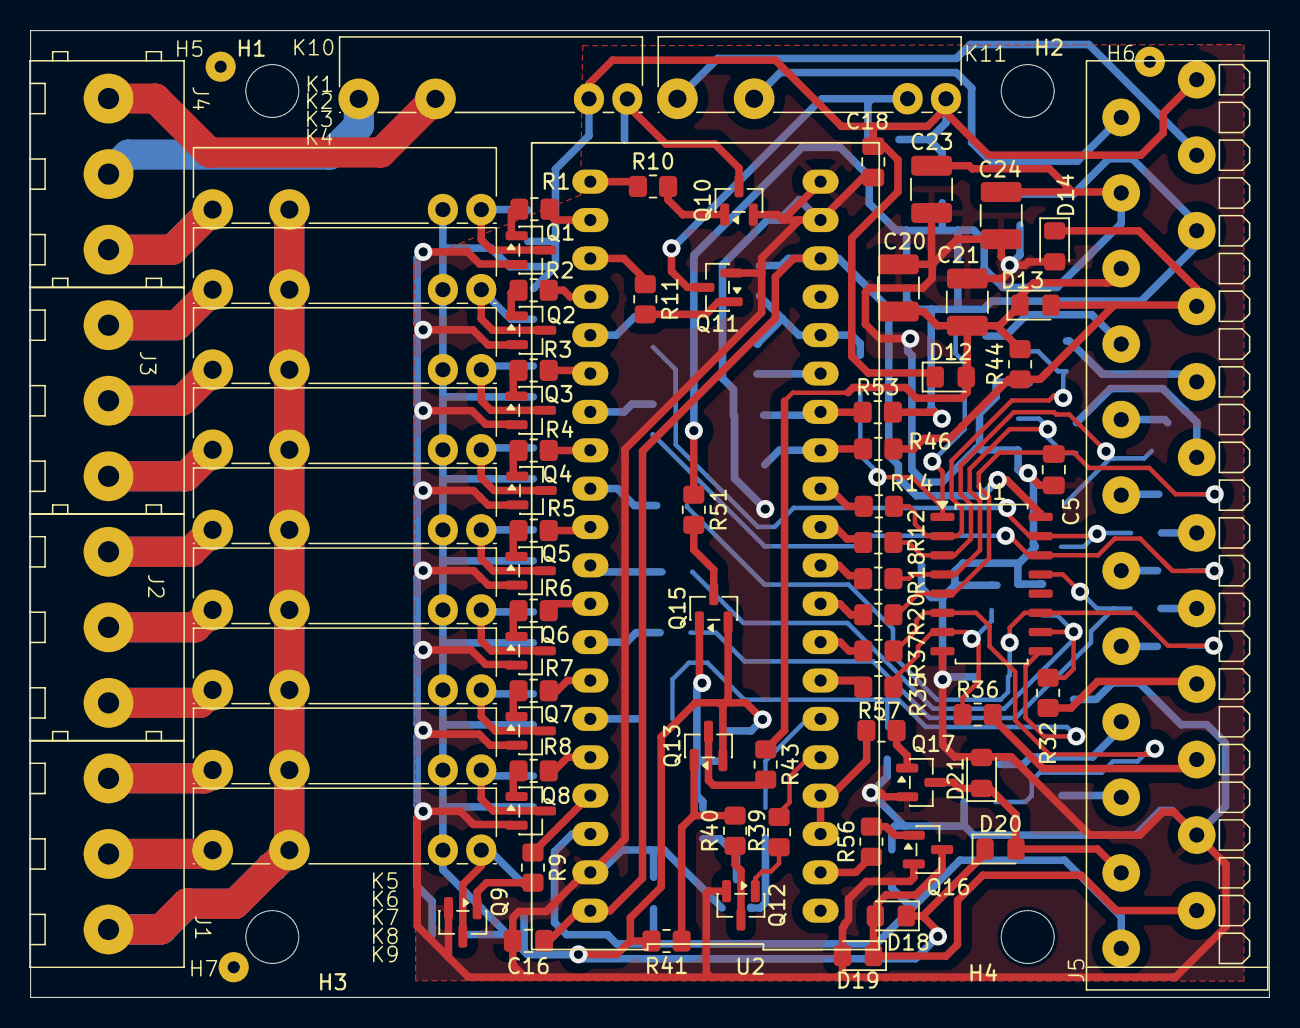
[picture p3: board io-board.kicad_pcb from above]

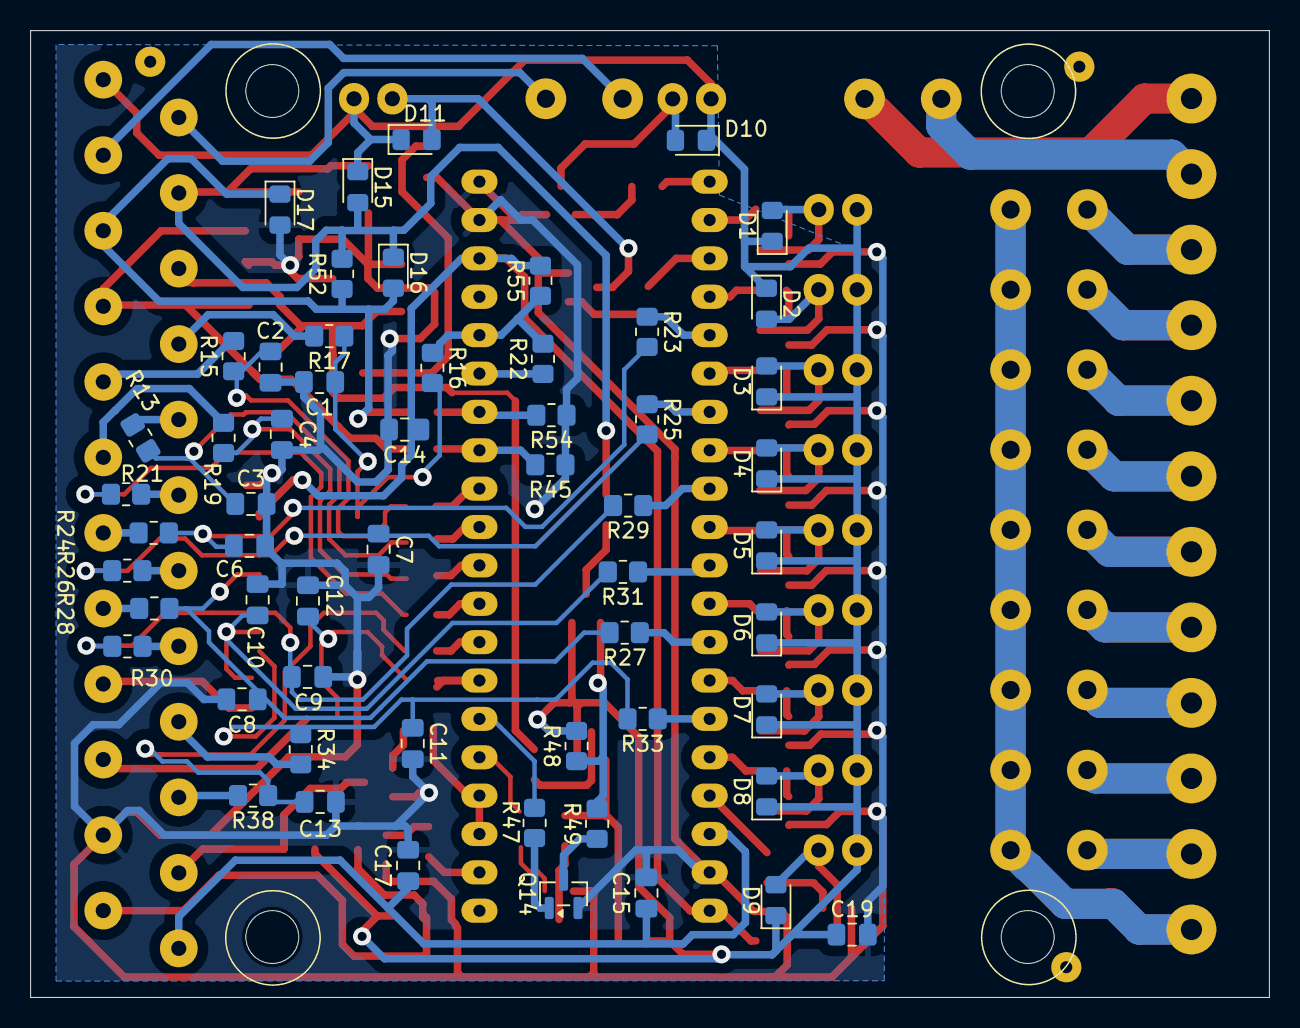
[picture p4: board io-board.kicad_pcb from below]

Board: 2 copper layers, 82.0 x 64.0 mm, 141 parts (57 on the bottom side), 113 nets.

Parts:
C1, C2, C3, C4, C5, C6, C7, C8, C9, C10, C11, C12, C13, C14, C15, C16, C17, C18, C19: C; C_0805_2012Metric_Pad1.18x1.45mm_HandSolder
C20, C21, C23, C24: C; C_1210_3225Metric_Pad1.33x2.70mm_HandSolder
D1, D2, D3, D4, D5, D6, D7, D8, D9, D10, D11, D12, D13, D14, D15, D16, D17, D18, D19, D20, D21: D; D_0805_2012Metric_Pad1.15x1.40mm_HandSolder
H1, H2, H3, H4: MountingHole; MountingHole_3.5mm
H5, H6, H7: Conn_01x01; stencil-holder
J1, J2, J3, J4: Conn_01x03; DG128-5.0-03P-14-00A-H
J5: Conn_01x24; PTSA-0.5-24-2.5-Z
K1, K2, K3, K4, K5, K6, K7, K8, K9, K10, K11: FRM18A-5 DC12V; FRM18A-5
Q1, Q2, Q3, Q4, Q5, Q6, Q7, Q8, Q9, Q10, Q11, Q12, Q14, Q16, Q17: NPN; SOT-23
Q13, Q15: PNP; SOT-23
R1, R2, R3, R4, R5, R6, R7, R8, R9, R10, R11, R12, R13, R14, R15, R16, R17, R18, R19, R20, R21, R22, R23, R24, R25, R26, R27, R28, R29, R30, R31, R32, R33, R34, R35, R36, R37, R38, R39, R40, R41, R43, R44, R45, R46, R47, R48, R49, R51, R52, R53, R54, R56, R57: R; R_0805_2012Metric_Pad1.20x1.40mm_HandSolder
R55: 50K; R_0805_2012Metric_Pad1.20x1.40mm_HandSolder
U1: Littelfuse SP720; SOIC-16_4.55x10.3mm_P1.27mm
U2: Kamod BluePill STM32F103C8T6; Kamod-BluePill-STM32F103C8T6

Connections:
+3.3V: C14.1, C16.1, R55.2, U1.16, U2.18, U2.40
+5V: C15.1, C17.1, J5.1, U2.38
+12V: C18.1, C19.1, D1.1 (K), D2.1 (K), D3.1 (K), D4.1 (K), D5.1 (K), D6.1 (K), D7.1 (K), D8.1 (K), D9.1 (K), D10.1 (K), D11.1 (K), D12.1 (K), D15.1 (K), D18.1 (K), D20.1 (K), J5.24, K1.A2, K2.A2, K3.A2, K4.A2, K5.A2, K6.A2, K7.A2, K8.A2, K9.A2, K10.A2, K11.A1, Q13.2 (E), Q15.2 (E), R41.2, R48.2
/ESD1: C1.1, R16.2, R17.1, U1.1
/ESD2: C2.1, R14.2, R15.1, U1.2
/ESD3: C3.1, R12.2, R13.1, U1.3
/ESD4: C4.1, R18.2, R19.1, U1.4
/ESD5: C5.1, R20.2, R21.1, U1.5
/ESD6: C13.1, R37.2, R38.1, U1.6
/ESD7: C12.1, R35.2, R36.1, U1.7
/ESD8: C11.1, R33.2, R34.1, U1.9
/ESD9: C10.1, R31.2, R32.1, U1.10
/ESD10: C9.1, R29.2, R30.1, U1.11
/ESD12: C8.1, R27.2, R28.1, U1.13
/ESD13: C7.1, R25.2, R26.1, U1.14
/ESD14: C6.1, R23.2, R24.1, U1.15
/IO1: J5.16, R15.2
/IO2: J5.15, R13.2
/IO3: J5.14, R19.2
/IO4: J5.13, R21.2
/IO5: J5.12, R24.2
/IO6: J5.11, R26.2
/IO7: J5.10, R28.2
/IO8: J5.9, R30.2
/IO9: J5.8, R32.2
/IO10: J5.7, R34.2
/IO11: J5.6, R36.2
/IO12: J5.5, R38.2
/IO-IN1: R14.1, U2.12
/IO-IN2: R12.1, U2.11
/IO-IN3: R18.1, U2.10
/IO-IN4: R20.1, U2.9
/IO-IN5: R23.1, U2.25
/IO-IN6: R25.1, U2.27
/IO-IN7: R27.1, U2.33
/IO-IN8: R29.1, U2.29
/IO-IN9: R31.1, U2.31
/IO-IN10: R33.1, U2.35
/IO-IN11: R35.1, U2.7
/IO-IN12: R37.1, U2.8
/LED1-FB: R45.2, R46.1, U2.13
/LED1-M: D13.2 (A), D14.1 (K), J5.18, R44.1, R46.2
/LED1-P: C20.1, C21.1, D12.2 (A), D13.1 (K), J5.19, R43.1, R44.2
/LED1-PWM: R39.1, U2.5
/LED2-FB: R53.1, R54.2, U2.14
/LED2-M: D16.2 (A), D17.1 (K), J5.20, R52.1, R53.2
/LED2-P: C23.1, C24.1, D15.2 (A), D16.1 (K), J5.21, R51.1, R52.2
/LED2-PWM: R47.1, U2.6
/OC1: D18.2 (A), D19.1 (K), J5.2, Q16.3 (C)
/OC1-IN: R56.1, U2.2
/OC2: D20.2 (A), D21.1 (K), J5.3, Q17.3 (C)
/OC2-IN: R57.1, U2.3, U2.4
/Relays/REL1-OUT: J4.3, K1.14
/Relays/REL2-OUT: J3.1, K2.14
/Relays/REL3-OUT: J3.2, K3.14
/Relays/REL4-OUT: J3.3, K4.14
/Relays/REL5-OUT: J2.1, K5.14
/Relays/REL6-OUT: J2.2, K6.14
/Relays/REL7-OUT: J2.3, K7.14
/Relays/REL8-OUT: J1.1, K8.14
/Relays/REL9-OUT: J1.2, K9.14
/Relays/REL10-OUT1: J4.1, K10.13
/Relays/REL10-OUT2: J4.2, K10.14
/Relays/REL-COM: J1.3, K1.13, K2.13, K3.13, K4.13, K5.13, K6.13, K7.13, K8.13, K9.13
/UART: J5.17, R17.2
GND: C1.2, C2.2, C3.2, C4.2, C5.2, C6.2, C7.2, C8.2, C9.2, C10.2, C11.2, C12.2, C13.2, C14.2, C15.2, C16.2, C17.2, C18.2, C19.2, C20.2, C21.2, C23.2, C24.2, D14.2 (A), D17.2 (A), D19.2 (A), D21.2 (A), J5.4, Q1.2 (E), Q2.2 (E), Q3.2 (E), Q4.2 (E), Q5.2 (E), Q6.2 (E), Q7.2 (E), Q8.2 (E), Q9.2 (E), Q10.2 (E), Q11.2 (E), Q12.2 (E), Q14.2 (E), Q16.2 (E), Q17.2 (E), R45.1, R54.1, U1.8, U2.19, U2.20, U2.39
unnamed: D1.2 (A), K1.A1, Q1.3 (C)
unnamed: D2.2 (A), K2.A1, Q2.3 (C)
unnamed: D3.2 (A), K3.A1, Q3.3 (C)
unnamed: D4.2 (A), K4.A1, Q4.3 (C)
unnamed: D5.2 (A), K5.A1, Q5.3 (C)
unnamed: D6.2 (A), K6.A1, Q6.3 (C)
unnamed: D7.2 (A), K7.A1, Q7.3 (C)
unnamed: D8.2 (A), K8.A1, Q8.3 (C)
unnamed: D9.2 (A), K9.A1, Q9.3 (C)
unnamed: D10.2 (A), K10.A1, Q10.3 (C)
unnamed: D11.2 (A), K11.A2, Q11.3 (C)
unnamed: Q1.1 (B), R1.2
unnamed: Q2.1 (B), R2.2
unnamed: Q3.1 (B), R3.2
unnamed: Q4.1 (B), R4.2
unnamed: Q5.1 (B), R5.2
unnamed: Q6.1 (B), R6.2
unnamed: Q7.1 (B), R7.2
unnamed: Q8.1 (B), R8.2
unnamed: Q9.1 (B), R9.2
unnamed: Q10.1 (B), R10.2
unnamed: Q11.1 (B), R11.2
unnamed: Q12.1 (B), R39.2
unnamed: Q12.3 (C), R40.1
unnamed: Q13.1 (B), R40.2, R41.1
unnamed: Q13.3 (C), R43.2
unnamed: Q14.1 (B), R47.2
unnamed: Q14.3 (C), R49.1
unnamed: Q15.1 (B), R48.1, R49.2
unnamed: Q15.3 (C), R51.2
unnamed: Q16.1 (B), R56.2
unnamed: Q17.1 (B), R57.2
REL1-IN: R1.1, U2.22
REL2-IN: R2.1, U2.24
REL3-IN: R3.1, U2.26
REL4-IN: R4.1, U2.28
REL5-IN: R5.1, U2.30
REL6-IN: R6.1, U2.32
REL7-IN: R7.1, U2.34
REL8-IN: R8.1, U2.36
REL9-IN: R9.1, U2.37
REL10-IN: R10.1, U2.21
REL11-IN: R11.1, U2.23
REL11-OUT1: J5.22, K11.14
REL11-OUT2: J5.23, K11.13
RXD: R16.1, R22.2, R55.1, U2.16
TXD: R22.1, U2.15

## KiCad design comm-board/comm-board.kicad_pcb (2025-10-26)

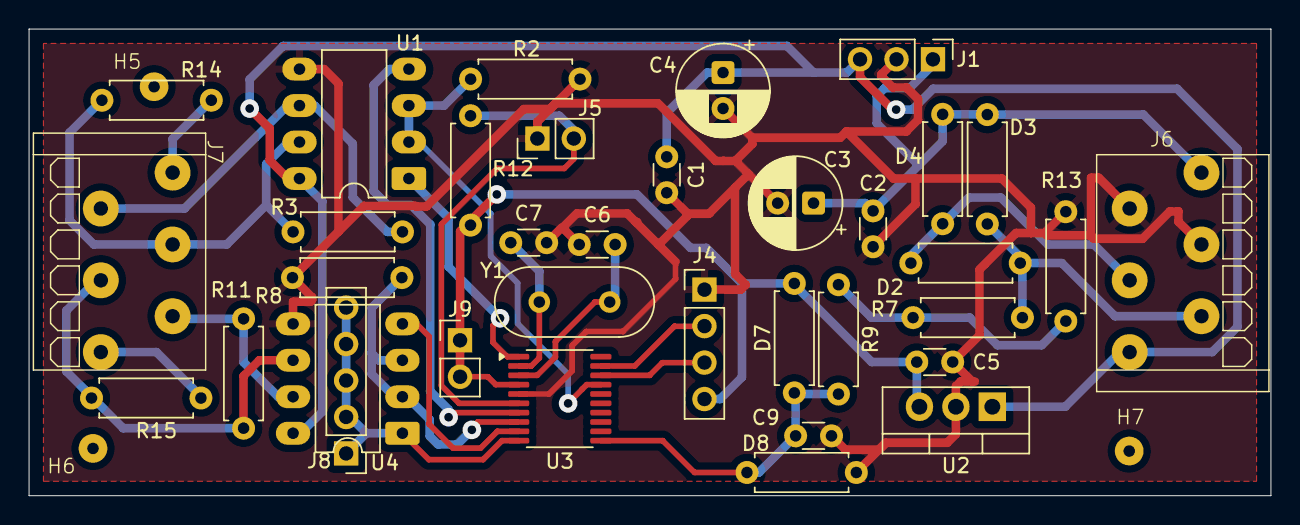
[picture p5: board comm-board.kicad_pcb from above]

Board: 2 copper layers, 86.5 x 32.5 mm, 38 parts (0 on the bottom side), 25 nets.

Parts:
C1, C2, C5, C6, C7, C9: C_Disc_D3.0mm_W1.6mm_P2.50mm
C3, C4: C_Polarized; CP_Radial_D6.3mm_P2.50mm
D2, D7, D8: D; R_Axial_DIN0207_L6.3mm_D2.5mm_P7.62mm_Horizontal
D3, D4: D_Schottky; R_Axial_DIN0207_L6.3mm_D2.5mm_P7.62mm_Horizontal
H5, H6, H7: Conn_01x01; stencil-holder
J1: Step Down 5V; PinHeader_1x03_P2.54mm_Vertical
J4: ST-LINK; PinHeader_1x04_P2.54mm_Vertical
J5, J9: Conn_01x02; PinHeader_1x02_P2.54mm_Vertical
J6: Power; PTSA-0.5-6-2.5-Z
J7: Communication; PTSA-0.5-6-2.5-Z
J8: PinHeader_1x05_P2.54mm_Vertical
R2, R8: 20K; R_Axial_DIN0207_L6.3mm_D2.5mm_P7.62mm_Horizontal
R3, R11: 50K; R_Axial_DIN0207_L6.3mm_D2.5mm_P7.62mm_Horizontal
R7, R9, R12, R13, R14, R15: 120; R_Axial_DIN0207_L6.3mm_D2.5mm_P7.62mm_Horizontal
U1, U4: MAX485E; DIP-8_W7.62mm_LongPads
U2: LF33_TO220; TO-220-3_Vertical
U3: STM32C011F4Px; TSSOP-20_4.4x6.5mm_P0.65mm
Y1: Crystal; Crystal_HC18-U_Vertical

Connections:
+3.3V: C5.1, D7.1 (K), J4.4, J9.1, J9.2, R12.2, U2.3 (VO), U3.4 (VDD)
+5V: C1.1, C4.1, J1.3, J6.1, U1.8 (VCC), U2.1 (VI), U4.8 (VCC)
+12V: C2.1, C3.1, D3.1 (K), D4.1 (K), J1.1, J6.6
/DE1: R2.1, U1.2 (~RE), U1.3 (DE), U3.17 (PA10/PA12)
/DE2: R8.1, U3.8 (PA1), U4.2 (~RE), U4.3 (DE)
/DI1: U1.4 (DI), U3.7 (PA0)
/DI2: U3.9 (PA2), U4.4 (DI)
/LOCAL+12V: D2.2 (A), D3.2 (A), J6.2, R7.2
/POWER_SENSE: C9.1, D7.2 (A), D8.1 (K), R9.1, U3.11 (PA4)
/REMOTE+12V: D2.1 (K), D4.2 (A), J6.3
/RESET: J5.2, R12.1, U3.6 (PF2)
/RO1: U1.1 (RO), U3.1 (PB7)
/RO2: J8.1, J8.2, J8.3, J8.4, J8.5, U3.10 (PA3), U4.1 (RO)
/RS-485-A1: J7.2, R3.1, U1.6 (A)
/RS-485-A2: J7.4, R11.1, R15.1, U4.6 (A)
/RS-485-B1: J7.3, R3.2, R14.1, U1.7 (B)
/RS-485-B2: J7.5, R11.2, U4.7 (B)
/SWCLK: J4.2, U3.19 (PA14)
/SWDIO: J4.3, U3.18 (PA13)
GND: C1.2, C2.2, C3.2, C4.2, C5.2, C6.2, C7.2, C9.2, D8.2 (A), J1.2, J4.1, J5.1, J6.4, J6.5, R2.2, R8.2, R13.1, U1.5 (GND), U2.2 (GND), U3.5 (VSS), U4.5 (GND)
unnamed: J7.1, R14.2
unnamed: J7.6, R15.2
unnamed: R7.1, R9.2, R13.2
unnamed: C7.1, U3.2 (PC14), Y1.2
unnamed: C6.1, U3.3 (PC15), Y1.1

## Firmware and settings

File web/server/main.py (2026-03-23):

#!/usr/bin/env python

import os
import re
import http
import json
import base64
from pathlib import Path
import signal
import asyncio

from websockets.exceptions import ConnectionClosed
from websockets.datastructures import Headers
from websockets.asyncio.server import serve, ServerConnection, Request, Response
from urllib.parse import urlparse

from serve_file import serve_file

from commands import execute_command
from ecdsa import ecdsa_verify
from session import Session
from addresses import alloc_address, on_disconnect
from serial_daemon import start as start_serial_daemon, stop as stop_serial_daemon, set_data_received_callback
from data_link import init as init_data_link, deinit as deinit_data_link


# ---------- Session Registry ----------

_sessions = []  # Global list of active sessions
_sessions_lock = asyncio.Lock()


async def register_session(session):
    """Register a new session"""
    async with _sessions_lock:
        _sessions.append(session)


async def unregister_session(session):
    """Unregister a session on disconnect"""
    async with _sessions_lock:
        _sessions.remove(session)


async def broadcast_to_sessions(message):
    """Broadcast a message to all connected sessions"""
    async with _sessions_lock:
        for session in _sessions:
            await session.send_queue.put(message)


async def handler(websocket: ServerConnection):
    try:
        ch2 = os.urandom(32)
        await websocket.send(json.dumps({"type": "challenge", "challenge": ch2.hex()}))
        response = json.loads(await websocket.recv())
        if response.get("type") != "challenge_response" or len(str(response.get("signature"))) != 128:
            raise Exception("Invalid response")
        sig2 = str(response.get("signature"))
        # Verify signature sig2 with public key (x, y) on message ch2
        with open(Path(__file__).parent.parent / "auth.json", 'r') as f:
            authData = json.load(f)
        x = int(authData['x'], 16)
        y = int(authData['y'], 16)
        r = int(sig2[:64], 16)
        s = int(sig2[64:], 16)
        ok = ecdsa_verify(x, y, r, s, ch2)
        if not ok:
            raise Exception("Invalid signature")
        address_token = response.get("address_token")
        if not isinstance(address_token, str):
            address_token = None
        result = alloc_address(address_token)
        if result is None:
            await websocket.send(json.dumps({"type": "error", "message": "No address available"}))
            return
        address, token = result
        session = Session(websocket, address)
        await websocket.send(json.dumps({"type": "challenge_accepted", "address": address, "token": token}))
        await register_session(session)
        
        # Task to send queued messages to this client
        async def send_loop():
            try:
                while True:
                    message = await session.send_queue.get()
                    await websocket.send(json.dumps(message))
            except (ConnectionClosed, asyncio.CancelledError):
                pass
            except Exception as e:
                print(f"Error in send loop: {e}")
        
        send_task = asyncio.create_task(send_loop())
        try:
            while True:
                message = await websocket.recv()
                await execute_command(session, message)
        finally:
            send_task.cancel()
            on_disconnect(session)
            await unregister_session(session)
    except ConnectionClosed as e:
        pass
    except Exception as e:
        print("Error in handler:", e)
    finally:
        try:
            await websocket.close()
        except:
            pass


# ---------- Callbacks ----------

async def data_received(data: bytes):
    """Called by serial daemon when data is received from serial port.
    Broadcasts the data to all connected clients.
    """
    message = {
        "type": "recv",
        "data": base64.b64encode(data).decode('ascii')
    }
    await broadcast_to_sessions(message)


def process_request(connection: ServerConnection, request: Request):
    global challenges
    path = urlparse(request.path).path
    path = path.split('/')
    path = map(lambda x: re.sub(r'[^a-z0-9._-]', '', x, flags=re.IGNORECASE), path)
    path = filter(lambda x: x != '' and not x.startswith('.'), path)
    path = '/' + '/'.join(path)
    if path == '/':
        path = '/index.html'
    if path == '/connect':
        cookie = list(filter(lambda x: x[0].lower() == 'cookie', request.headers.items()))
        if len(cookie) != 1:
            return connection.respond(http.HTTPStatus.FORBIDDEN, 'Forbidden')
        cookie_value = cookie[0][1]
        match = re.search(r'connectKey=([0-9a-fA-F]{128})', cookie_value)
        if match is None:
            return connection.respond(http.HTTPStatus.FORBIDDEN, 'Forbidden')
        sig1 = match.group(1).lower()
        with open(Path(__file__).parent.parent / "auth.json", 'r') as f:
            authData = json.load(f)
        ch1 = bytes.fromhex(authData['ch1'])
        x = int(authData['x'], 16)
        y = int(authData['y'], 16)
        # Verify signature sig1 with public key (x, y) on message ch1
        r = int(sig1[:64], 16)
        s = int(sig1[64:], 16)
        ok = ecdsa_verify(x, y, r, s, ch1)
        if not ok:
            print("Invalid signature")
            return connection.respond(http.HTTPStatus.FORBIDDEN, 'Forbidden')
        return None
    else:
        return serve_file(path.strip('/'), connection, request)

async def main():
    port = int(os.environ.get("PORT", "8001"))
    # Register callback before starting daemon
    set_data_received_callback(data_received)
    try:
        await start_serial_daemon()
        await init_data_link()
    except Exception as e:
        print(f"Failed to start serial daemon: {e}")
        raise
    try:
        async with serve(handler, "", port, process_request=process_request) as server:
            loop = asyncio.get_running_loop()
            loop.add_signal_handler(signal.SIGTERM, server.close)
            await server.wait_closed()
    finally:
        await deinit_data_link()
        await stop_serial_daemon()


if __name__ == "__main__":
    asyncio.run(main())

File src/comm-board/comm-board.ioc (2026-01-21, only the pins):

Mcu.UserName=STM32C011F6Px
PA1.Signal=GPIO_Input
PA2.Signal=USART2_TX
PA3.Signal=USART2_RX
PA4.Signal=ADC1_IN4

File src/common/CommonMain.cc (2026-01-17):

#include <stdio.h>
#include <stdarg.h>

#include "HW.hh"
#include "UART.hh"
#include "Time.hh"
#include "WorkQueue.hh"


IdleWork demo([](IdleWork*) {
//    auto t = Time::get32();
//    auto tt = Time::getPrecise32();
//    printf("- %d %d\n", t, tt);
});


UART uart(&huart2);

extern "C"
void commonMain()
{
    uart.init();
    //demo.run();
    Work::mainLoop();
}

__attribute__((naked))
uint32_t semiCall(uint32_t funcCode, uint32_t param0)
{
    asm __volatile__ ("BKPT 0xAB\nBX lr":::"memory");
}

static char buffer[512];
static int bufferPos = 0;

static void flush(DelayedWork* x = nullptr)
{
    // Flush buffer
    if (bufferPos > 0) {
        //semiCall(0x04, (uint32_t)"----FLUSH3----\r\n");
        buffer[bufferPos] = 0;
        semiCall(0x04, (uint32_t)buffer);
        bufferPos = 0;
    }
}


DelayedWork flushWork(flush, Work::LOW);


void myprintf(const char* fmt, ...)
{
    va_list args;

    va_start(args, fmt);
    int len = vsnprintf(&buffer[bufferPos], sizeof(buffer) - bufferPos, fmt, args);
    va_end(args);

    if (len < 0) {
        buffer[bufferPos] = 0;
    } else if (len < (int)(sizeof(buffer) - bufferPos)) {
        bufferPos += len;
    } else {
        va_list args;
        //semiCall(0x04, (uint32_t)"----FLUSH2----\r\n");
        flush();
        va_start(args, fmt);
        len = vsnprintf(&buffer[bufferPos], sizeof(buffer) - bufferPos, fmt, args);
        va_end(args);
        if (len < 0) {
            bufferPos = 0;
        } else if (len < (int)(sizeof(buffer) - bufferPos)) {
            bufferPos += len;
        } else {
            buffer[sizeof(buffer) - 1] = 0;
            bufferPos = sizeof(buffer) - 1;
        }
    }

    if (sizeof(buffer) - bufferPos < 32) {
        //semiCall(0x04, (uint32_t)"----FLUSH1----\r\n");
        flushWork.cancel();
        flush();
    } else {
        Time::update();
        flushWork.run(500, false);
    }
}

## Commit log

2025-09-29 Add KiCad board project
    [IO.kicad_sch, Relays.kicad_sch, io-board.kicad_pcb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]
2025-09-29 Add STM32 module
    [Relays.kicad_sch, io-board.kicad_pcb, io-board.kicad_sch]
2025-09-29 Almost all connected except OC and LED drivers
    [IO.kicad_sch, Relays.kicad_sch, io-board.kicad_pcb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]
2025-09-30 All added and connected in PCB. Cleanup needed.
    [IO.kicad_sch, LED_Driver.kicad_sch, OC.kicad_sch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]
2025-10-01 PCB: All component locations done
    [io-board.kicad_pcb, io-board.kicad_sch]
2025-10-03 PCB: All in place, need to prepare for production
    [io-board.kicad_pcb]
2025-10-03 PCB: Stencil holders and production configuration
    [io-board.kicad_pcb, io-board.kicad_sch]
2025-10-03 PCB: Fixups
    [io-board.kicad_pcb]
2025-10-05 PCB: comm-board draft
    [RS485.kicad_sch, comm-board.kicad_pcb, comm-board.kicad_sch]
2025-10-05 PCB: comm: Cleanup and production configuration
    [RS485.kicad_sch, comm-board.kicad_pcb, comm-board.kicad_sch]
2025-10-05 PCB: comm: Add stencil holder
    [comm-board.kicad_pcb, comm-board.kicad_sch]
2025-10-26 PCB: comm: Arranged components labels
    [comm-board.kicad_pcb]
2025-10-26 PCB: io: Removed unneeded res in LED driver
    [LED_Driver.kicad_sch, io-board.kicad_pcb]
2025-10-27 Enhance README with STM32 UART practical approaches
    Added practical approach examples for STM32 UART communication.
2025-11-03 Add SET_NAME functionality for device name change
2025-12-30 PCB: comm-board: component values and BOM
    [BOM.ods, RS485.kicad_sch, comm-board.kicad_sch]
2026-01-01 PCB: io-board: component values and BOM
    [BOM.ods, IO.kicad_sch, LED_Driver.kicad_sch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]
2026-01-02 PCB: small BOM updates
    [BOM.ods, io-board.kicad_pcb]
2026-01-11 Initial sources and unit tests with coverage
    [BOM.ods]
2026-01-17 First drafts of soft for comm-board
    [BOM.ods, comm-board (Debug).cfg, comm-board (Release).cfg]
2026-01-21 New CAN-based physical layer, application protocol description, hi-res timers drafts.
    [IO.kicad_sch, io-board.kicad_sch]
2026-01-24 CAN extension PCB for comm-board
    [comm-board-ext.kicad_pcb, comm-board-ext.kicad_sch]
2026-02-23 comm-board-ext: Modified for CNC milling
    [comm-board-ext.kicad_pcb, comm-board-ext.kicad_sch]
2026-03-11 Enhance protocol with new frame structure option
    Added option for frame structure to improve transmission reliability and reduce collision probability.
2026-03-11 Clarify frame validation and timing logic
    Updated frame transmission checks and timing calculations.
2026-03-15 Add ESC masking to mask variable in packet.cpp
    Apply ESC masking to the mask variable before processing data.
2026-03-16 comm-board: New "Gateway" and "Router" extensions and removed old "Universal"
    [comm-board-ext-gw.kicad_pcb, comm-board-ext-gw.kicad_sch, comm-board-ext-router.kicad_pcb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]
2026-03-16 Enhance bootloader functionality and configuration
    - Updated CPU clock frequency from 24MHz to 48MHz in project settings.
    - Increased FLASH memory size from 6K to 16K in linker script.
    - Added RNG (Random Number Generator) implementation with functions for generating and adding entropy.
    - Modified main.c to integrate RNG and adjust timing calculations.
    - Revised UART settings and added overrun detection disable feature for USART1 and USART2.
    - Cleaned up project configuration file by removing unnecessary CRC parameters.
2026-03-16 Add bootloader programming functionality and UART communication
    - Implemented programming commands (init, erase, write, read, reset) in prog.c.
    - Defined device information structure for STM32C011xx.
    - Created UART communication functions for data transmission and reception in uart.c.
    - Removed unused RNG functionality by deleting rng.c.
    - Added header file for programming commands and UART interface.
    - Enhanced packet handling with CRC validation and escape sequences for UART communication.
    [main.c, uart.c]
2026-03-16 Refactor UART communication and add support for PortState structure
2026-03-16 Refactor bootloader code and update project settings
    - Updated .cproject and .settings/stm32cubeide.project.prefs to reflect new configurations.
    - Added NUM_PORTS definition to support multiple USART ports in uart.c.
    - Removed cfg.h and prog.c files as they were no longer needed.
    - Refactored uart.c to improve structure and readability, including initialization and command handling.
    - Updated linker script STM32C011F6PX_FLASH.ld to adjust RAM size for magic value.
    - Enhanced uartPoll function to handle multiple USART ports and added packet handling logic.
    - Introduced boot selection logic to determine application start based on stack pointer and vector table.
    - Added CRC calculation and mask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
    [main.c, uart.c]
2026-03-16 Refactor bootloader and test application: update CRC calculation, modify UART output type, and adjust GPIO settings
2026-09-23 Enhance physical layer section with UART details
    Updated UART specifications to include 1-wire and 2-wire options.
2026-09-23 Clarify 2-wire UART connection and access negotiation
    Added clarification about UART connection and access negotiation.
2026-09-24 Refactor tx pin monitoring and event handling
    Updated the start_tx_pin_monitor function to connect an external interrupt and clear EXTI_PR. Adjusted event handling to check for timer events and current line state.
2026-09-25 Optimize timer event logic in async_send_negotiator
    Refactor timer event handling in startup sequence and remove unnecessary checks.
